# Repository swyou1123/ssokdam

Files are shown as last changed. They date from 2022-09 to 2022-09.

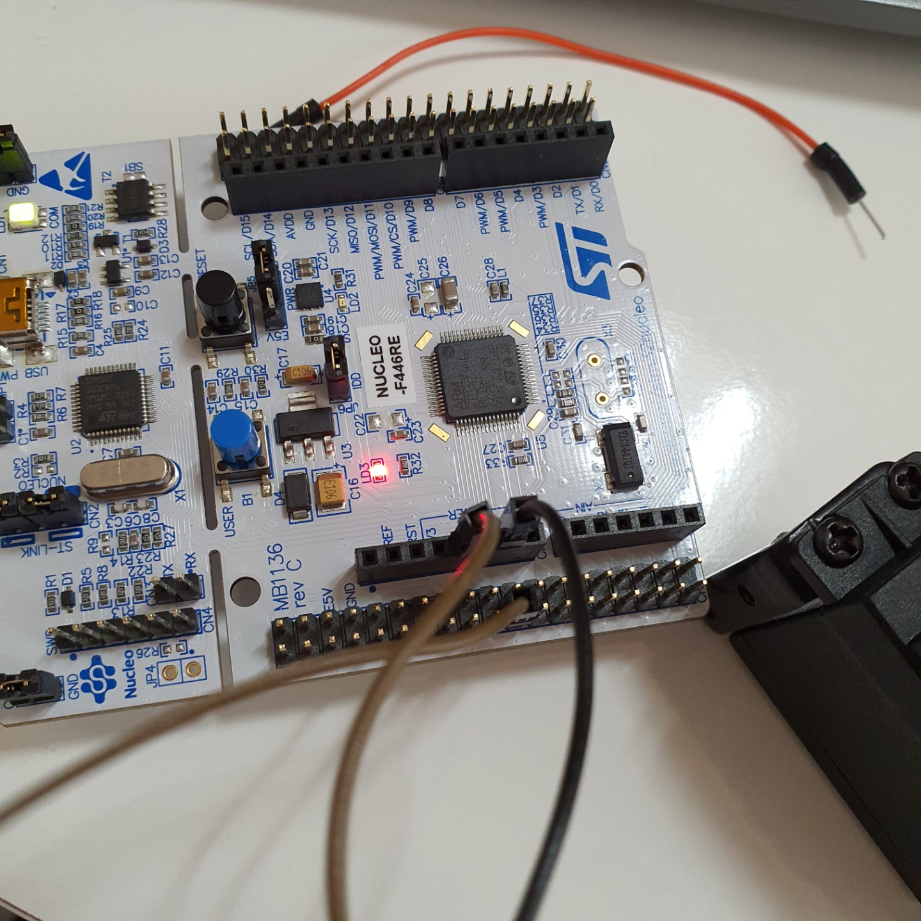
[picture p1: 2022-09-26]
Embedded/STM32/NUCLEO-F446RE/Motor/Servo_Motor/Reference/pinout.jpg

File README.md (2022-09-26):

벨루생선

<div align="center">
  <h1>담배꽁초처리 플랫폼 SSOKDAM</h1>
</div>

## 🧾목차

1. [**서비스 소개**](#-서비스-소개)
2. [**기술 스택**](#%EF%B8%8F-기술-스택)
3. [**시스템 아키텍처**](#-시스템-아키텍쳐)
4. [**웹 주요기능 및 데모영상**](#-웹-주요기능-및-데모영상)
5. [**디바이스 주요기능**](#%EF%B8%8F-디바이스-주요기능)
6. [**UCC 보러가기**](#-ucc-보러가기)
7. [**협업 관리**](#-협업-관리)
8. [**개발 멤버 소개**](#-개발-멤버-소개)
9. [**프로젝트 기간**](#-프로젝트-기간)
10. [**프로젝트 관련 문서**](#-프로젝트-관련-문서)

<br/>

## ✨ 서비스 소개

#### 심각한 바다의 오염문제 😖

> 국내 하루 평균 길에 버려지는 담배꽁초가 무려 **1250**만 개비라고 합니다.<br />
>
> 담배가 그대로 하수구를 통해 바다에 유입돼 바다오염이 되고<br />
>
> 그렇게 바다에서 분해된 미세플라스틱은 오롯이 인간이 먹게됩니다..

#### 바다오염의 해결책 담배꽁초수거 플랫폼 SSOKDAM 💊

##### 바다를 오염시키는 무분별한 담배 꽁초로 부터 지구를 지키기 위해 SSOKDAM을 이용해주세요!

</br>

</br>

## 🛠️ 기술 스택

 <br>

    <br>
    <br/>Styled Components (https://camo.githubusercontent.com/41326de293d3848e2ab0f29bf1680427128757fe6b586ceddf1097cb4eeb5ff7/68747470733a2f2f696d672e736869656c64732e696f2f62616467652f7374796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) HTML5 (https://camo.githubusercontent.com/49fbb99f92674cc6825349b154b65aaf4064aec465d61e8e1f9fb99da3d922a1/68747470733a2f2f696d672e736869656c64732e696f2f62616467652f68746d6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) CSS3 [![Recoil](https://camo.githubusercontent.com/469d51dd03eb2bea7080300247476ae376048af66c8040c2047afa2312e2c052/68747470733a2f2f696d672e736869656c64732e696f2f62616467652f5265636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)](https://camo.githubusercontent.com/469d51dd03eb2bea7080300247476ae376048af66c8040c2047afa2312e2c052/68747470733a2f2f696d672e736869656c64732e696f2f62616467652f5265636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) 

 





</br>

</br>

## 🎛 시스템 아키텍쳐

7 광주_1반_C106조_시스템개략도



#### ERD



#### Backend 디렉토리 구조

```
├─main
│  │   
│  ├─java                
│  │  └─com
│  │      └─ssafy
│  │          └─project
│  │              ├─config        # CORS 및 암호화 설정 폴더
│  │              ├─controller    # 각 도메인별 컨트롤러 있는 폴더
│  │              ├─domain       # 각 DB 테이블 을 설정한 도메인 폴더
│  │              ├─Function      # 추가적인 기능을 모아둔 폴더
│  │              ├─Repository   # 도메인별 JPA Repository 설정한 폴더
│  │              └─Service        # 도메인별 기능을 정의해둔 폴더 
│  └─resources
└─test
    └─java
        └─com
            └─ssafy
                └─project            # 테스트 케이스 있는 폴더
```

#### Frontend 디렉토리 구조

```
───src
    ├─api  		# 백엔드 통신과 필요한 api들을 모아놓은 폴더
    ├─db   		# 백엔드와 통신전에 미리 가상DB를 만들어 테스트를 하는 폴더
    ├─Pages 	# 랜더링되는 페이지가 모아져있는 폴더 
    │  ├─Admin 	# 관리자 페이지가 들어 있는 폴더
    │  │  ├─AdminComplain 	# 불만사항 관련한 관리자 폴더
    │  │  ├─AdminNotice  	# 공지사항 관련한 관리자 폴더
    │  │  └─components 		# 관리자 페이지에서 랜더링되는데 필수적으로 필요한 요소들이 있는 폴더
    │  ├─Auth 		# 회원가입, 로그인 등 인증, 권한과 관련된 페이지가 있는 폴더
    │  ├─Loading 	# 로딩페이지 폴더
    │  ├─Main 		# Client단의 모든 페이지가 있는 폴더
    │  ├─Nav 		# Client단의 Nav바가 있는 폴더
    │  └─Sub 		# Client단에서 부수적으로 필요한 페이지가 있는 폴더
    ├─picture 		# 화면의 사진이 저장돼있는 폴더
    ├─styles 		# 여러가지 style component들이 있는 폴더
    └─ui 			# 간단한 modal이 있는 폴더
```

</br>

</br>

</br>

## 💻 웹 주요기능 및 데모영상

### 1. 회원가입시 외부 API을 이용한 성인인증 및 계좌인증 기능

<div style="display : flex; justify-content : center;">
    
</div>

<div style="display : flex; justify-content : center;">
    
</div>

- 담배와 관련된 서비스이기 때문에 보다 확실한 성인인증 절차를 위해 외부인증 API(iamport)를 이용하여 휴대전화에 등록된 정보에 기반한 성인인증 서비스를 구현하였습니다. 
- 포인트 환전시 현금을 지급해 주어야하기에 본인인증 정보에 기반한 계좌인증 절차를 만들어 확실한 본인의 계좌로 회원가입이 되게 만들었습니다. 

###  2. 디바이스 찾기

<div style="display : flex; justify-content : center;">
    
</div>

- 저희 서비스를 이용하기 위해선 주변에 있는 디바이스를 찾아야합니다. 주변에 있는 디바이스를 탐색하기 위해 지도 API를 이용하여 가장 가까운 디바이스의 위치를 파악하게 하였습니다.
- 지도에 띄워진 사용하기 버튼을 누르면 바로 사용할 수 있게 QR체크 화면으로 넘어갑니다.

###  3. QR접근

<div style="display : flex; justify-content : center;">
    
</div>

- 디바이스를 사용하기 위해 디바이스에 부착된 QR을 찍으면 디바이스 고유번호를 인식하여 디바이스가 열리게 하였습니다.
- 디바이스가 열리고 담배를 투입하면 디바이스 내부로직을 통해 담배여부를 확인하고 결과를 넘겨주게 만들었습니다.
- 담배가 맞다면 "성공페이지"로 아니라면 "실패페이지"로 이동합니다.
- 담배가 맞다면 유저의 최근담배핀 시간이 갱신되게 되고 포인트가 적립이 됩니다.
- 홈화면으로 이동시 다음 이용 가능시간(마지막으로 피고 40분 후)까지 체크를 위해 타이머기능이 있습니다.
- 40분이 지났다면 이용가능, 40분이 지나지 않았다면 타이머가 시작됩니다.

### 4. 포인트적립 및 환전기능

<div style="display : flex; justify-content : center;">
    
</div>

<div style="display : flex; justify-content : center;">
    
</div>

<div style="display : flex; justify-content : center;">
    
</div>

- 담배를 넣어서 포인트가 적립되었다면 포인트 전환신청을 할 수 있습니다.
- 전환신청 내역은 관리자 페이지에 올라가게 되고 관리자가 승인을 해주면 계좌에 돈 입금과 동시에 알림이 가게 됩니다.

### 5. 불만사항접수(불편사항 & 고장신고)

<div style="display : flex; justify-content : center;">
    
</div>
<div style="display : flex; justify-content : center;">
    
</div>

- 불편사항 발생시 글과 내용(이미지 첨부도 가능)을 적게 됩니다. 적힌 글은 관리자 페이지에 올라가게 됩니다.
- 고장사항 발생시에는 글과 내용뿐만 아니라 어디 디바이스인지에 관한 정보가 있어야하기 때문에 QR체크로 디바이스 등록까지 마쳐야 글을 작성할 수 있습니다. 역시 작성된 글을 관리자 페이지로 올라가게 됩니다.
- 고장신고된 디바이스는 관리자가 글을 보며 즉석에서 디바이스 고장상태로 변환시킬 수 있고 고장상태로 변환된 디바이스는 기기정보창에서 빨간색으로 표시가 됩니다.

### 6. 관리자 페이지 디바이스 관리기능

<div style="display : flex; justify-content : center;">
    
</div>

- 문제가 생긴디바이스나 고장난 디바이스를 관리하게 위해 지도상에 설치된 디바이스를 볼 수 있습니다.
- 문제가 생긴디바이스가 있다면 최적경로로 이동하기 위해 네이버지도 api를 통해 최단경로시간을 안내합니다.
- 디바이스 주변동네를 구체적으로 보고 싶다면 로드뷰 기능을 활용할 수도 있습니다.
- 디바이스를 잘 조치했다면 고장상태를 변경할 수 있습니다.

## 🎛️ 디바이스 주요기능

### 0. 디바이스 이미지




###  1. 투입구 개폐

open

- 사용자가 디바이스 상단에 위치한 QR코드를 인식합니다. 사용자 인것이 DB측과의 지속적인 GET요청을 통하여 확인이 되면 내부의 모터가 작동하며 투입구와 내부 덮개가 열리게 됩니다. 이후 담배 인식이 되면 개폐구는 닫히게 됩니다.

###  2. 담배 인식 및 판별

sensor

- 인식부에서는 CDS 조도 센서를 사용하여, 물체가 입구를 통과 할 경우 낮아지는 조도량을 측정하여 
물체 통과를 인식합니다. 인식되지 않을경우 5초후 다음 과정은 생략됩니다.
- 판별부에서는 정확도를 높이기 위해 3가지 센서를 사용하여 담배인지 아닌지를 판별합니다. 
- 비접촉 온도센서에서는 적정 설정온도를, 가스 센서에서는 일정량 이상의 가스를, 공기질 센서에서는 미세먼지 량을 측정하여 3가지 판별 프로세스 중 하나라도 통과하면 담배로 인식됩니다. 

###  3. 담배 분쇄

grind

- 판별부에서 담배로 인식이 된다면 곧바로 분쇄하게 됩니다. 분쇄된 담배는 일반 쓰레기와 분리되어 수거됩니다.

###  4. 처리 후 사용 정보 DB 송신

get

- 판별이 끝난 후 담배 인것이 확인되면 이를 DB측으로 송신합니다. 
- DB에서는 이를 포인트로 적립시킵니다.

###  5. 기기정보 업로드



- 1시간 마다 기기의 정보를 업로드합니다. 
- 위의 이미지 처럼 DB의 Table에 해당되는 JSON 형식으로 POST요청을 보냅니다. 기기 ID, 사용자 이름, 기기 상태, 쓰레기 통 용량, 배터리 등의 정보를 관리자 측으로 송신합니다.

</br>

</br>

## 🎥 UCC 보러가기

[보러가기](https://www.youtube.com/watch?v=OL8DLIg1nm4)

</br>

</br>

## 🙌 협업 관리







## 🧑‍💻 개발 멤버 소개

<table>
    <tr>
        <td height="140px" align="center"> <a href="https://github.com/Owenkim9720">
             <br><br> 👑 김도원 <br>(Embedded) </a> <br></td>
        <td height="140px" align="center"> <a href="https://github.com/kiki249049">
             <br><br> 🙂 김강현 <br>(Front-End) </a> <br></td>
        <td height="140px" align="center"> <a href="https://github.com/dm0114">
             <br><br> 😆 권덕민 <br>(Front-End) </a> <br></td>
        <td height="140px" align="center"> <a href="https://github.com/swyou1123">
             <br><br> 😁 유승우 <br>(Back-End) </a> <br></td>
        <td height="140px" align="center"> <a href="https://github.com/yoonseonghan">
             <br><br> 🙄 윤성한 <br>(Embedded) </a> <br></td>
    </tr>
    <tr>
        <td align="center">Firmware<br/>3D Modeling</td>
        <td align="center">UI/UX<br/>React</td>
        <td align="center">UI/UX<br/>React</td>
        <td align="center">REST API<br/>CI/CD<br/>Infra<br/></td>
        <td align="center">Firmware</td>
    </tr>
</table>

## ⌛ 프로젝트 기간

### 22.7.11 ~ 22.8.19

- 기획 및 설계 : 22.7.11 ~ 20
- 프로젝트 구현 : 22.7.21 ~ 22.8.16
- 버그 수정 및 산출물 정리 : 22.8.17 ~ 19

## 📖 프로젝트 관련 문서

| 구분 | 링크 |
| --- | --- |
| 와이어프레임 | [웹 와이어프레임 바로가기](/outputs/1.광주_1반_C106조_와이어프레임.pdf)  /  [디바이스 와이어프레임 바로가기](/outputs/3.광주_1반_C106조_임베디드_와이어프레임.pdf) |
| 프로젝트 노션 | [프로젝트 노션 바로가기](https://inquisitive-warrior-3ad.notion.site/PJT1_-IOT-ba584e2f93cf41d8aa36975c0ef51f42) |
| DB덤프 | [DB덤프 바로가기](/exec/03_DB덤프.sql) |
| ERD | [ERD 바로가기](https://www.erdcloud.com/d/fKA2qjd6gNFftuiW6) |
| 빌드/배포 | [빌드/배포 바로가기](/exec/01_광주_1반_C106_빌드%20및배포.pdf) |
| 외부서비스 정보 | [외부서비스 정보 바로가기](/exec/02_광주_1반_C106_외부_서비스_정보.pdf) |
| 시연 시나리오 | [시연 시나리오 바로가기](/exec/04_광주_1반_시연시나리오.pdf) |
| 발표자료 | [발표자료 바로가기](https://drive.google.com/file/d/12lOU1-kJ9XMx_7HsXzjGJ9VWt4gaxyYJ/view) |

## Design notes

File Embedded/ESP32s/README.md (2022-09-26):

ESP32관련 코드 (Arduino file)

Save Convention
1. 테스한 센서 및 모터이름을 디렉토리로 영어로 설정 (ex. /Embedded/Esp32/Sensor/GPS_Sensor) (ex. /Embedded/Esp32/Motor/Servo) 
2. 세부디렉토리(ex. /Embedded/Esp32/Motor/Servo)에는.ino 파일 & md파일 (총2개의 파일로 업로드)
3. 추가적으로 설명이 필요한 부분은 md파일을 이용, 내용을 정리해둔다
4. 이미지 및 동영상 첨부가 필요한경우 Reference파일을 만들어 넣어둔다

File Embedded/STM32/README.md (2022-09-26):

STM32관련 코드 (Cube IDE file)

Save Convention
0. 사용한 보드 이름 디렉토리 들어가기
1. 테스한 센서 및 모터이름을 디렉토리로 영어로 설정 (ex. /Embedded/Esp32/Sensor/GPS_Sensor) (ex. /Embedded/Esp32/Motor/Servo) 
2. 세부디렉토리(ex. /Embedded/Esp32/Motor/Servo)에는 CubeIDE의 Package파일 & md파일 (총2개의 파일로 업로드)
3. 추가적으로 설명이 필요한 부분은 md파일을 이용, 내용을 정리해둔다
4. 이미지 및 동영상 첨부가 필요한경우 Reference파일을 만들어 넣어둔다

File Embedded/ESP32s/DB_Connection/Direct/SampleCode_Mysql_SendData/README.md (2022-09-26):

ESP32s 보드를 이용, 여러 센서데이터를 MySQL 데이터베이스에 올리는 샘플 코드입니다.
해당파일의 "Credential.h" 부분의 내용을 변경하여 사용가능하며, ino파일의 쿼리문을 필요에 맞게 변경하시면 됩니다.

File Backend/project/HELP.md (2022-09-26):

# Getting Started

### Reference Documentation
For further reference, please consider the following sections:

* [Official Gradle documentation](https://docs.gradle.org)
* [Spring Boot Gradle Plugin Reference Guide](https://docs.spring.io/spring-boot/docs/2.7.1/gradle-plugin/reference/html/)
* [Create an OCI image](https://docs.spring.io/spring-boot/docs/2.7.1/gradle-plugin/reference/html/#build-image)
* [Spring Web](https://docs.spring.io/spring-boot/docs/2.7.1/reference/htmlsingle/#web)
* [Thymeleaf](https://docs.spring.io/spring-boot/docs/2.7.1/reference/htmlsingle/#web.servlet.spring-mvc.template-engines)
* [Spring Boot DevTools](https://docs.spring.io/spring-boot/docs/2.7.1/reference/htmlsingle/#using.devtools)
* [Spring Data JPA](https://docs.spring.io/spring-boot/docs/2.7.1/reference/htmlsingle/#data.sql.jpa-and-spring-data)

### Guides
The following guides illustrate how to use some features concretely:

* [Building a RESTful Web Service](https://spring.io/guides/gs/rest-service/)
* [Serving Web Content with Spring MVC](https://spring.io/guides/gs/serving-web-content/)
* [Building REST services with Spring](https://spring.io/guides/tutorials/rest/)
* [Handling Form Submission](https://spring.io/guides/gs/handling-form-submission/)
* [Accessing Data with JPA](https://spring.io/guides/gs/accessing-data-jpa/)
* [Accessing data with MySQL](https://spring.io/guides/gs/accessing-data-mysql/)

### Additional Links
These additional references should also help you:

* [Gradle Build Scans – insights for your project's build](https://scans.gradle.com#gradle)

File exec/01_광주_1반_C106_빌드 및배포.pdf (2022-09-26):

# 빌드 및 배포

## 프로젝트 기간 : 2022:07.04 ~ 8.19

# 삼성SW청년아카데미 광주캠퍼스 7기

## 김도원 김강현 권덕민 윤성한 유승우 정혜원

# 1. 기술스택

구분 | 기술스택 | 상세내용 | 버전

공통

형상관리 | Mattermost, Notion gitlab Jira | - 이슈관리 - 커뮤니케이션 -
BackEnd | DB | MySQL | 5.8
JPA | -
| Java | Spring Boot Zulu | 2.7.2 - Spring
| IDE | IntelliJ | 2022.2
| Build | Gradle | 7.4.1
| WebRTC | Tomcat | 9.0.64
| HTML5 | | - CSS3 -
| JavaScript(ES6) | | -
| IDE | Visual Studio Code | 1.63.2
| mui/material | | 5.9.1
| tanstack/react-query | | 4.0.10
| axios | | 0.27.2
| firebase | | 9.9.2
| formik | | 2.2.9
| kakao | | 0.4.1
| react-kakao-maps-sdk | | 1.1.1
| react-qr-reader | | 2.2.1
| recoil | | 0.7.4
| recoil-persist | | 4.2.0
| sass | | 1.54.1
| react-router-dom | | 6.3.0
| styled-components | | 5.3.5
| yup | | 0.32.11

### FrontEnd

Server | 서버 | AWS EC2 Ubuntu | 20.04.4 LTS - 플랫폼
| 배포 | Docker | 20.10.17
| | Jenkins | 2.364.2

# 2. 상세 내용

□ 개요

아래 그림은 “ssokdam” 서비스의 배포환경 및 CI/CD 배포 흐름도입니다. 팀원들이 각자 작성한 프로젝트를 GitLab에 push 하면, Jenkins Build

Trigger를 통해 FrontEnd와 BackEnd를 빌드하게 됩니다.

Embedded | ESP32 | GPS Sensor | TinyGPSPlus 1.03
| | AirQuailty Sensor
| | WiFi
| | Temp Sensor
| | Gas Sensor
| | CRUD | Arduino JSON 0.10
| | Servo motor | ESP Servo 1.0

<CI/CD 배포 환경>

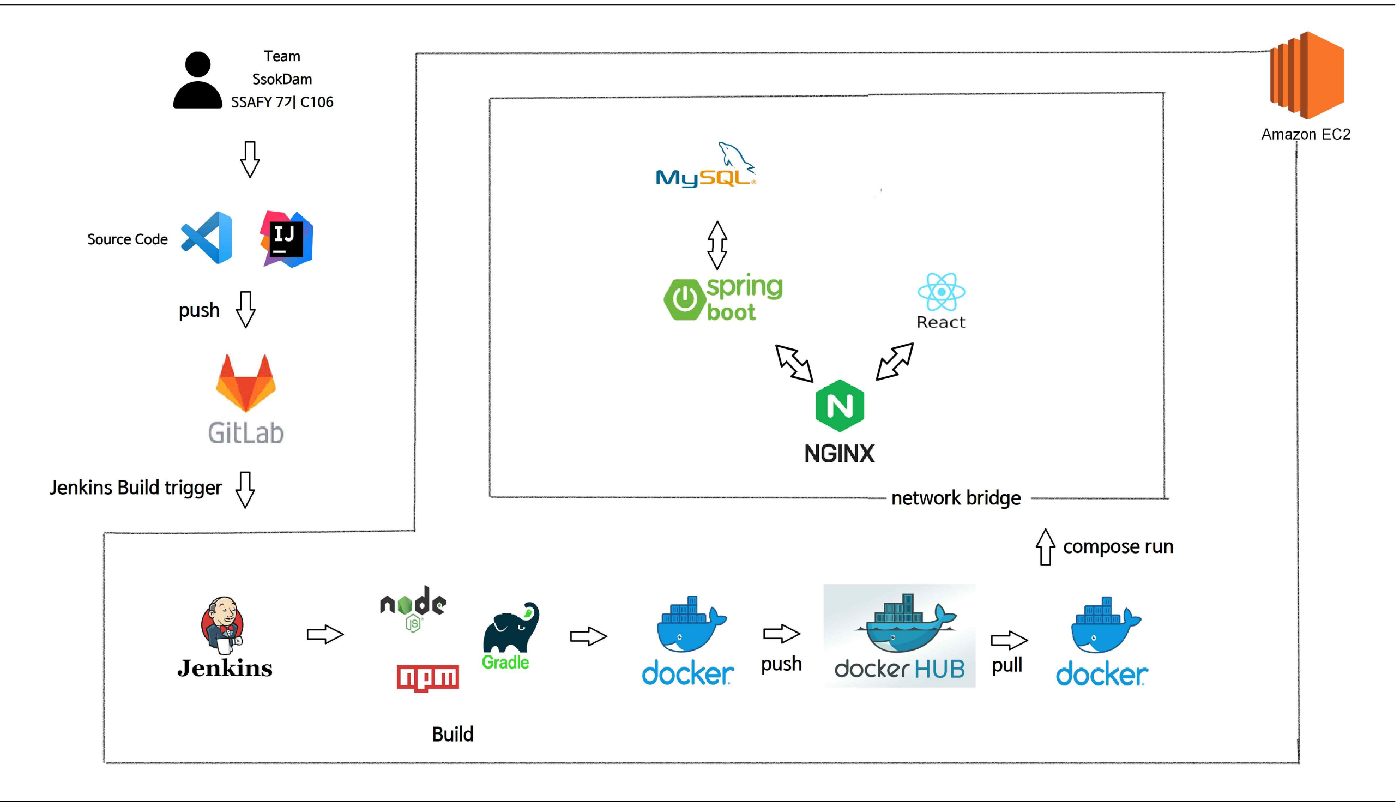
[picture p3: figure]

### 각 프로젝트를 빌드 후에는 Docker 이미지를 만들고 이를 Docker Hub에

### push 합니다. Docker Hub로부터 서비스에 필요한 이미지를 받아와 컨테 이너로 띄웁니다. SSAFY에서 지원받은 EC2 싱글 인스턴스로 인프라를 구 축했습니다. 추후 서비스화를 위해 Nginx는 리버스 프록시 서버로 설정하

### 였습니다. 동시에 Nginx 서버로부터 9090 포트를 BackEnd 서버로 설정 하여 구축했습니다. □ FrontEnd

ㅇ Docker 이미지 생성을 위해 Dockerfile을 작성합니다.

### (해당 파일은 프로젝트 내에 이미 작성되어있습니다.)

### ㅇ docker 이미지 생성

### □ Backend ㅇ Gradle 빌드

ㅇ Docker 이미지 생성을 위해 Dockerfile을 작성합니다.

### (해당 파일은 프로젝트 내에 이미 작성되어있습니다.)

### ㅇ docker 이미지 생성

FROM node:alpine
WORKDIR "/Frontend/usr/src/app"
COPY package.json ./
RUN npm install --save --legacy-peer-deps COPY ./ ./
CMD ["npm","run","start"]

FROM openjdk:17-jdk-alpine
ADD /build/libs/project-0.0.1-SNAPSHOT.jar app.jar ENV JAVA_OPTS=""
ENTRYPOINT ["java","-jar","/app.jar"]

docker build –t syou1123/react:0.1 .

docker build –t syou1123/springboot:0.1 .

./gradlew build

### □ Docker-compose

ㅇ Docker 이미지 생성을 위해 Dockerfile을 작성합니다.

### (해당 파일은 프로젝트 내에 이미 작성되어있습니다.)

version: '3'
services:
nginx:
image: nginx:1.21.5-alpine ports:
- 80:80
- 443:443
volumes:
- /etc/nginx/nginx.conf:/etc/nginx/nginx.conf
- /var/log/nginx:/var/log/nginx
- /etc/letsencrypt:/etc/letsencrypt
- /etc/localtime:/etc/localtime:ro -e TZ=Asia/Seoul - /etc/localtime:/etc/localtime:ro
- /usr/share/zoneinfo/Asia/Seoul:/etc/timezone:ro container_name: myweb-proxy
depends_on:
- web
- api web:

image: swyou1123/react:0.1 ports:
- 3000:3000
volumes:
- /etc/localtime:/etc/localtime:ro -e TZ=Asia/Seoul - /etc/localtime:/etc/localtime:ro
- /usr/share/zoneinfo/Asia/Seoul:/etc/timezone:ro container_name: myweb-web
**** 중략 ****

# 3. 프로퍼티 정의

### □ MySQL

### ㅇ 계정 생성

### ㅇ 스키마 생성

### □ Nginx

### ㅇ 환경 설정

create user 'swyou'@'%' identified by 'qudrlxksdir1!;
grant all privileges on *.* to 'swyou'@'%' with grant option; flush privileges

create database if not exists project collate utf8mb4_general_ci;

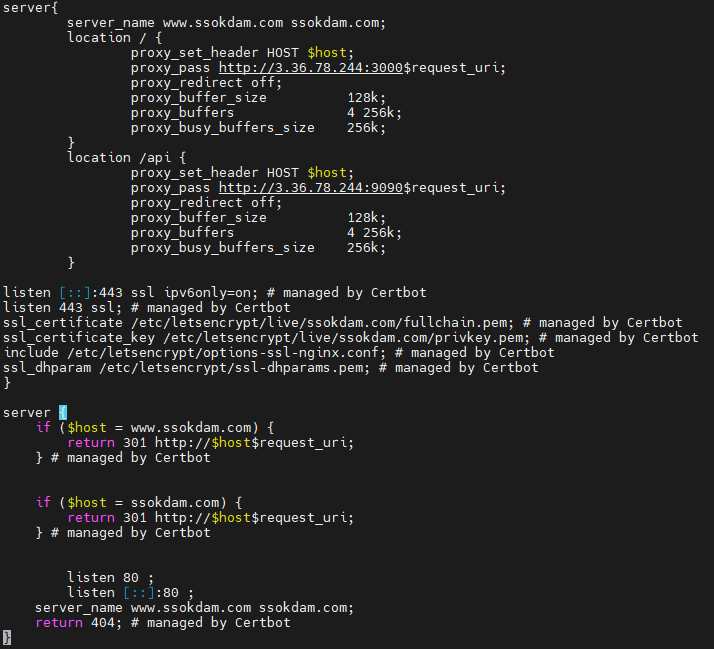
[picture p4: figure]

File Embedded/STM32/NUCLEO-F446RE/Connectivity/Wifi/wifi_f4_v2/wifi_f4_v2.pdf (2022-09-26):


26/07/2022

wifi_f4_v2 Project
Configuration Report

## 1. Description

### 1.1. Project

Project Name | wifi_f4_v2
Board Name | custom
Generated with: | STM32CubeMX 6.6.1
Date | 07/26/2022

### 1.2. MCU

MCU Series | STM32F4
MCU Line | STM32F446
MCU name | STM32F446RETx
MCU Package | LQFP64
MCU Pin number | 64

### 1.3. Core(s) information

Core(s) | Arm Cortex-M4

## 2. Pinout Configuration

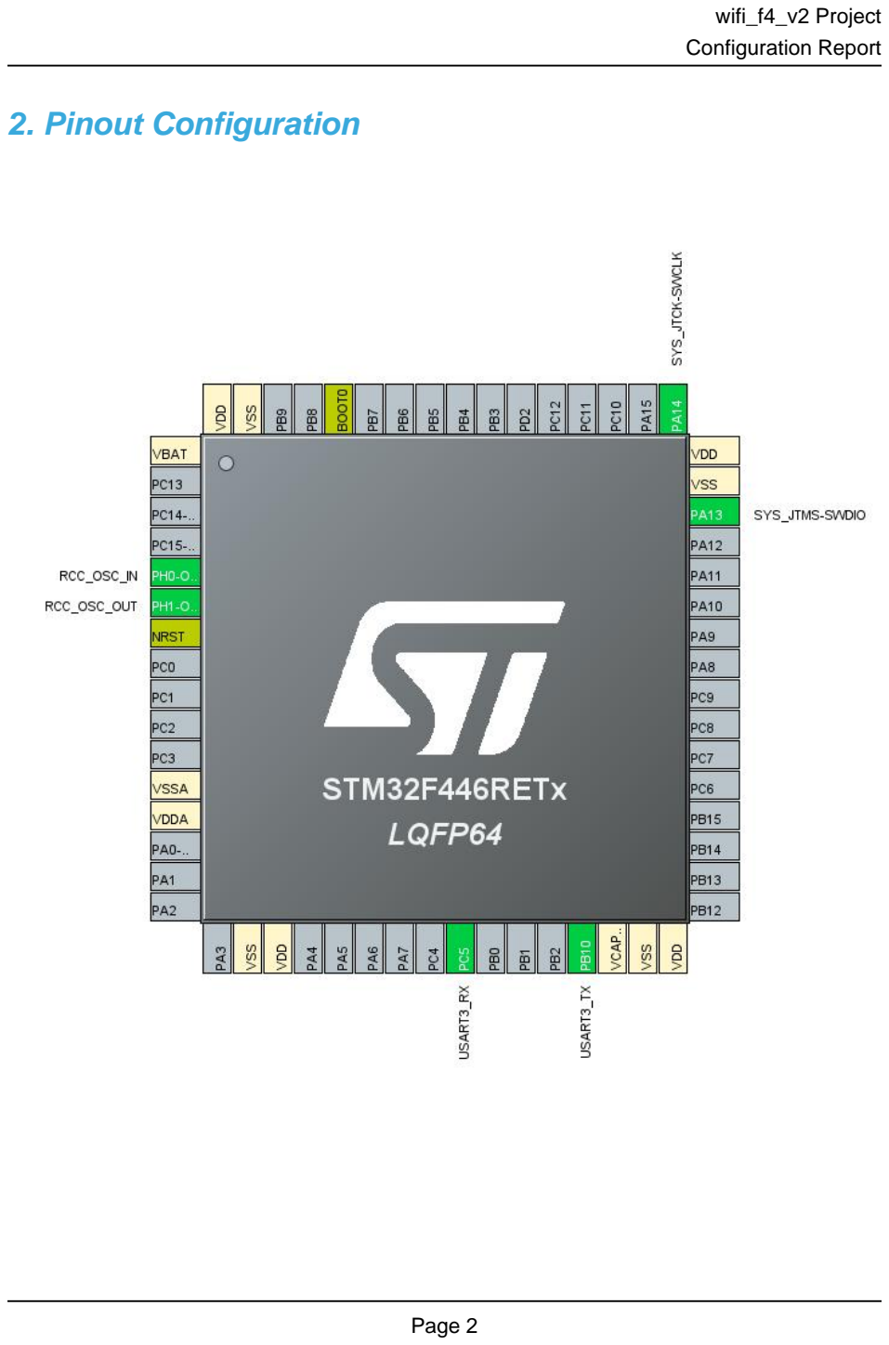
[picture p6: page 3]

## 3. Pins Configuration

Pin Number LQFP64 | Pin Name (function after reset) | Pin Type | Alternate Function(s) | Label
1 | VBAT | Power
5 | PH0-OSC_IN | I/O | RCC_OSC_IN
6 | PH1-OSC_OUT | I/O | RCC_OSC_OUT
7 | NRST | Reset
12 | VSSA | Power
13 | VDDA | Power
18 | VSS | Power
19 | VDD | Power
25 | PC5 | I/O | USART3_RX
29 | PB10 | I/O | USART3_TX
30 | VCAP_1 | Power
31 | VSS | Power
32 | VDD | Power
46 | PA13 | I/O | SYS_JTMS-SWDIO
47 | VSS | Power
48 | VDD | Power
49 | PA14 | I/O | SYS_JTCK-SWCLK
60 | BOOT0 | Boot
63 | VSS | Power
64 | VDD | Power

## 4. Clock Tree Configuration

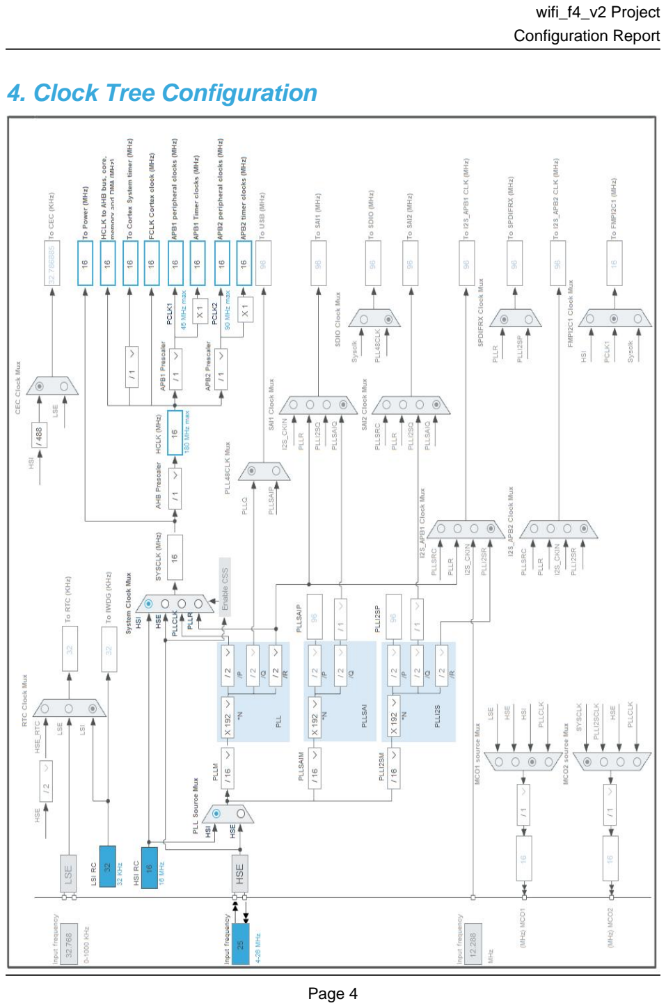
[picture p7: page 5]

## 5. Software Project

### 5.1. Project Settings

Name | Value
Project Name | wifi_f4_v2
Project Folder | C:\Users\multicampus\STM32CubeIDE\workspace_1.10.1\wifi_f4_v2
Toolchain / IDE | STM32CubeIDE
Firmware Package Name and Version | STM32Cube FW_F4 V1.27.1
Application Structure | Advanced
Generate Under Root | Yes
Do not generate the main() | No
Minimum Heap Size | 0x200
Minimum Stack Size | 0x400

### 5.2. Code Generation Settings

Name | Value
STM32Cube MCU packages and embedded software | Copy only the necessary library files
Generate peripheral initialization as a pair of '.c/.h' files | No
Backup previously generated files when re-generating | No
Keep User Code when re-generating | Yes
Delete previously generated files when not re-generated | Yes
Set all free pins as analog (to optimize the power consumption) | No
Enable Full Assert | No

### 5.3. Advanced Settings - Generated Function Calls

Rank | Function Name | Peripheral Instance Name
1 | SystemClock_Config | RCC
2 | MX_GPIO_Init | GPIO
3 | MX_USART3_UART_Init | USART3

## 6. Power Consumption Calculator report

### 6.1. Microcontroller Selection

Series | STM32F4
Line | STM32F446
MCU | STM32F446RETx
Datasheet | DS10693_Rev6

### 6.2. Parameter Selection

Temperature | 25
Vdd | 3.3

### 6.3. Battery Selection

Battery | Li-SOCL2(A3400)
Capacity | 3400.0 mAh
Self Discharge | 0.08 %/month
Nominal Voltage | 3.6 V
Max Cont Current | 100.0 mA
Max Pulse Current | 200.0 mA
Cells in series | 1
Cells in parallel | 1

### 6.4. Sequence

Step | Step1 | Step2
Mode | RUN | STOP_UDM (Under Drive)
Vdd | 3.3 | 3.3
Voltage Source | Battery | Battery
Range | Scale1-High | No Scale
Fetch Type | RAM/FLASH/REGON/ART/P REFETCH | n/a
CPU Frequency | 180 MHz | 0 Hz
Clock Configuration | HSE PLL | Regulator_LP Flash-PwrDwn
Clock Source Frequency | 4 MHz | 0 Hz
Peripherals
Additional Cons. | 0 mA | 0 mA
Average Current | 46 mA | 55 µA
Duration | 0.1 ms | 0.9 ms
DMIPS | 225.0 | 0.0
Ta Max | 98.02 | 104.99
Category | In DS Table | In DS Table

### 6.5. Results

Sequence Time | 1 ms | Average Current | 4.65 mA
Battery Life | 1 month | Average DMIPS | 225.0 DMIPS

### 6.6. Chart

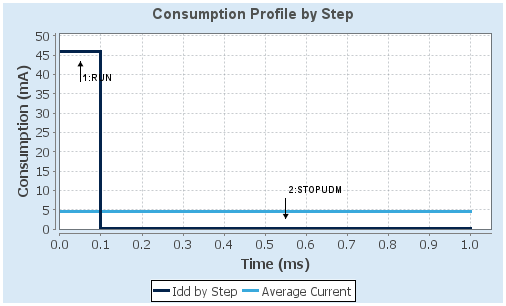
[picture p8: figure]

## 7. Peripherals and Middlewares Configuration

### 7.1. RCC

High Speed Clock (HSE): Crystal/Ceramic Resonator
7.1.1. Parameter Settings:

System Parameters:

VDD voltage (V) | 3.3
Instruction Cache | Enabled
Prefetch Buffer | Enabled
Data Cache | Enabled
Flash Latency(WS) | 0 WS (1 CPU cycle)
RCC Parameters:
HSI Calibration Value | 16
TIM Prescaler Selection | Disabled
HSE Startup Timout Value (ms) | 100
LSE Startup Timout Value (ms) | 5000
Power Parameters:
Power Regulator Voltage Scale | Power Regulator Voltage Scale 3
Power Over Drive | Disabled

### 7.2. SYS

Debug: Serial Wire

### 7.3. USART3

Mode: Asynchronous
7.3.1. Parameter Settings:

Basic Parameters:

Baud Rate | 115200
Word Length | 8 Bits (including Parity)
Parity | None
Stop Bits | 1
Advanced Parameters:
Data Direction | Receive and Transmit
Over Sampling | 16 Samples

* User modified value

## 8. System Configuration

### 8.1. GPIO configuration

IP | Pin | Signal | GPIO mode | GPIO pull/up pull down | Max Speed | User Label
RCC | PH0-OSC_IN | RCC_OSC_IN | n/a | n/a | n/a
| PH1-OSC_OUT | RCC_OSC_OUT | n/a | n/a | n/a
SYS | PA13 | SYS_JTMS-SWDIO | n/a | n/a | n/a
| PA14 | SYS_JTCK-SWCLK | n/a | n/a | n/a
USART3 | PC5 | USART3_RX | Alternate Function Push Pull | No pull-up and no pull-down | Very High *
| PB10 | USART3_TX | Alternate Function Push Pull | No pull-up and no pull-down | Very High *

### 8.2. DMA configuration

nothing configured in DMA service

### 8.3. NVIC configuration

8.3.1. NVIC
Interrupt Table | Enable | Preenmption Priority | SubPriority
Non maskable interrupt | true | 0 | 0
Hard fault interrupt | true | 0 | 0
Memory management fault | true | 0 | 0
Pre-fetch fault, memory access fault | true | 0 | 0
Undefined instruction or illegal state | true | 0 | 0
System service call via SWI instruction | true | 0 | 0
Debug monitor | true | 0 | 0
Pendable request for system service | true | 0 | 0
System tick timer | true | 15 | 0
USART3 global interrupt | true | 0 | 0
PVD interrupt through EXTI line 16 | unused
Flash global interrupt | unused
RCC global interrupt | unused
FPU global interrupt | unused
8.3.2. NVIC Code generation
Enabled interrupt Table | Select for init sequence ordering | Generate IRQ handler | Call HAL handler
Non maskable interrupt | false | true | false
Hard fault interrupt | false | true | false
Memory management fault | false | true | false
Pre-fetch fault, memory access fault | false | true | false
Undefined instruction or illegal state | false | true | false
System service call via SWI instruction | false | true | false
Debug monitor | false | true | false
Pendable request for system service | false | true | false
System tick timer | false | true | true
USART3 global interrupt | false | true | true

* User modified value

## 9. System Views

9.1. Category view
9.1.1. Current

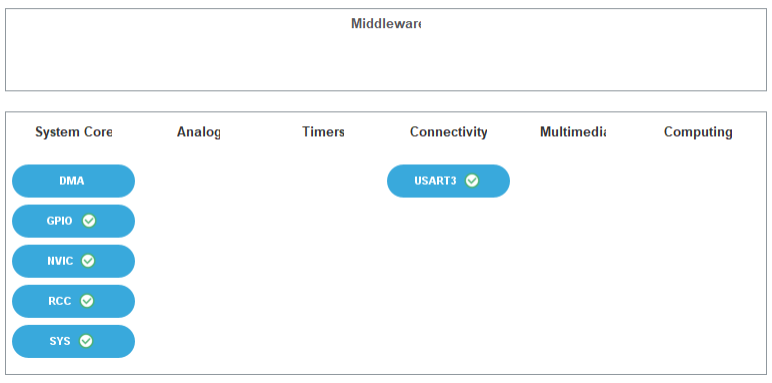
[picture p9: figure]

## 10. Docs & Resources

Type | Link
Presentations | https://www.st.com/resource/en/product_presentation/stm32-stm8_embedded_software_solutions.pdf
Presentations | https://www.st.com/resource/en/product_presentation/stm32_eval-tools_portfolio.pdf
Presentations | https://www.st.com/resource/en/product_presentation/stm32_stm8_functi onal-safety-packages.pdf
Presentations | https://www.st.com/resource/en/product_presentation/stm32-stm8_software_development_tools.pdf
Training Material | https://www.st.com/resource/en/sales_guide/sg_sc2154.pdf
Flyers | https://www.st.com/resource/en/flyer/flnucleolrwan.pdf
Flyers | https://www.st.com/resource/en/flyer/flstm32nucleo.pdf
Flyers | https://www.st.com/resource/en/flyer/flstmcsuite.pdf
Flyers | https://www.st.com/resource/en/flyer/flstm32trust.pdf
Product Certifications | https://www.st.com/resource/en/certification_document/stm32_authentication_can.pdf
Application Notes | https://www.st.com/resource/en/application_note/an1181-electrostatic-discharge-sensitivity-measurement-stmicroelectronics.pdf
Application Notes | https://www.st.com/resource/en/application_note/an1709-emc-design-guide-for-stm8-stm32-and-legacy-mcus-stmicroelectronics.pdf
Application Notes | https://www.st.com/resource/en/application_note/an2606-stm32-microcontroller-system-memory-boot-mode-stmicroelectronics.pdf
Application Notes | https://www.st.com/resource/en/application_note/an2639-soldering-recommendations-and-package-information-for-leadfree-ecopack-mcus-and-mpus-stmicroelectronics.pdf
Application Notes | https://www.st.com/resource/en/application_note/an2834-how-to-get-the-best-adc-accuracy-in-stm32-microcontrollers-stmicroelectronics.pdf
Application Notes | https://www.st.com/resource/en/application_note/an2867-oscillator-design-guide-for-stm8afals-stm32-mcus-and-mpus-stmicroelectronics.pdf
Application Notes | https://www.st.com/resource/en/application_note/an2945-stm8s-and-

| stm32-mcus-a-consistent-832bit-product-line-for-painless-migration-stmicroelectronics.pdf
Application Notes | https://www.st.com/resource/en/application_note/an3070-managing-the-driver-enable-signal-for-rs485-and-iolink-communications-with-the-stm32s-usart-stmicroelectronics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
Application Notes | https://www.st.com/resource/en/application_note/an3126-audio-and-waveform-generation-using-the-dac-in-stm32-products-stmicroelectronics.pdf
Application Notes | https://www.st.com/resource/en/application_note/an3154-can-protocol-used-in-the-stm32-bootloader-stmicroelectronics.pdf
Application Notes | https://www.st.com/resource/en/application_note/an3155-usart-protocol-used-in-the-stm32-bootloader-stmicroelectronics.pdf
Application Notes | https://www.st.com/resource/en/application_note/an3156-usb-dfu-protocol-used-in-the-stm32-bootloader-stmicroelectronics.pdf
Application Notes | https://www.st.com/resource/en/application_note/an3364-migration-and-compatibility-guidelines-for-stm32-microcontroller-applications-stmicroelectronics.pdf
Application Notes | https://www.st.com/resource/en/application_note/an3997-audio-playback-and-recording-using-the-stm32f4discovery-stmicroelectronics.pdf
Application Notes | https://www.st.com/resource/en/application_note/an3998-pdm-audio-software-decoding-on-stm32-microcontrollers-stmicroelectronics.pdf
Application Notes | https://www.st.com/resource/en/application_note/an4013-stm32-crossseries-timer-overview-stmicroelectronics.pdf
Application Notes | https://www.st.com/resource/en/application_note/an4031-using-the-stm32f2-stm32f4-and-stm32f7-series-dma-controller-stmicroelectronics.pdf
Application Notes | https://www.st.com/resource/en/application_note/an4221-i2c-protocol-used-in-the-stm32-bootloader-stmicroelectronics.pdf
Application Notes | https://www.st.com/resource/en/application_note/an4229-how-to-implement-a-vocoder-solution-using-stm32-microcontrollers-stmicroelectronics.pdf
Application Notes | https://www.st.com/resource/en/application_note/an4230-stm32- microcontroller-random-number-generation-validation-using-the-nist-

| statistical-test-suite-stmicroelectronics.pdf
Application Notes | https://www.st.com/resource/en/application_note/an4277-using-stm32-device-pwm-shutdown-features-for-motor-control-and-digital-power-conversion-stmicroelectronics.pdf
Application Notes | https://www.st.com/resource/en/application_note/an4286-spi-protocol-used-in-the-stm32-bootloader-stmicroelectronics.pdf
Application Notes | https://www.st.com/resource/en/application_note/an4488-getting-started-with-stm32f4xxxx-mcu-hardware-development-stmicroelectronics.pdf
Application Notes | https://www.st.com/resource/en/application_note/an4566-extending-the-dac-performance-of-stm32-microcontrollers-stmicroelectronics.pdf
Application Notes | https://www.st.com/resource/en/application_note/an4640-peripherals-interconnections-on-stm32f4057xx-stm32f4157xx-stm32f42xxx-stm32f43xxx-stm32f446xx-and-stm32f469479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
Application Notes | https://www.st.com/resource/en/application_note/an4655-virtually-increasing-the-number-of-serial-communication-peripherals-in-stm32-applications-stmicroelectronics.p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
Application Notes | https://www.st.com/resource/en/application_note/an4658-migration-of-applications-from-stm32f429439-lines-to-stm32f446-line-stmicroelectronics.pdf
Application Notes | https://www.st.com/resource/en/application_note/an4739-stm32cube-firmware-examples-for-stm32f4-series-stmicroelectronics.pdf
Application Notes | https://www.st.com/resource/en/application_note/an4750-handling-of-soft-errors-in-stm32-applications-stmicroelectronics.pdf
Application Notes | https://www.st.com/resource/en/application_note/an4759-using-the-hardware-realtime-clock-rtc-and-the-tamper-management-unit-tamp-with-stm32-microcontrollers-stmicroe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
Application Notes | https://www.st.com/resource/en/application_note/an4776-generalpurpose-timer-cookbook-for-stm32-microcontrollers-stmicroelectronics.pdf
Application Notes | https://www.st.com/resource/en/application_note/an4803-highspeed-si-simulations-using-ibis-and-boardlevel-simulations-using-hyperlynx-si-on-stm32-mcus-and-mpus-stmic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
Application Notes | https://www.st.com/resource/en/application_note/an4838-managing-memory-protection-unit-in-stm32-mcus-stmicroelectronics.pdf

Application Notes | https://www.st.com/resource/en/application_note/an4850-stm32-mcus-spreadspectrum-clock-generation-principles-properties-and-implementation-stmicroelectronics.pdf
Application Notes | https://www.st.com/resource/en/application_note/an4879-usb-hardware-and-pcb-guidelines-using-stm32-mcus-stmicroelectronics.pdf
Application Notes | https://www.st.com/resource/en/application_note/an4908-stm32-usart-automatic-baud-rate-detection-stmicroelectronics.pdf
Application Notes | https://www.st.com/resource/en/application_note/an4989-stm32-microcontroller-debug-toolbox-stmicroelectronics.pdf
Application Notes | https://www.st.com/resource/en/application_note/an4995-using-an-electromyogram-technique-to-detect-muscle-activity-stmicroelectronics.pdf
Application Notes | https://www.st.com/resource/en/application_note/an5020-digital-camera-interface-dcmi-on-stm32-mcus-stmicroelectronics.pdf
Application Notes | https://www.st.com/resource/en/application_note/an5027-interfacing-pdm-digital-microphones-using-stm32-mcus-and-mpus-stmicroelectronics.pdf
Application Notes | https://www.st.com/resource/en/application_note/an5036-thermal-management-guidelines-for-stm32-applications-stmicroelectronics.pdf
Application Notes | https://www.st.com/resource/en/application_note/an5073-receiving-spdif-audio-stream-with-the-stm32f4f7h7-series-stmicroelectronics.pdf
Application Notes | https://www.st.com/resource/en/application_note/an5156-introduction-to-stm32-microcontrollers-security-stmicroelectronics.pdf
Application Notes | https://www.st.com/resource/en/application_note/an5225-usb-typec-power-delivery-using-stm32-mcus-and-mpus-stmicroelectronics.pdf
Application Notes | https://www.st.com/resource/en/application_note/an5543-enhanced-methods-to-handle-spi-communication-on-stm32-devices-stmicroelectronics.pdf
Application Notes | https://www.st.com/resource/en/application_note/an4760-quadspi-interface-on-stm32-microcontrollers-and-microprocessors--stmicroelectronics.pdf
Application Notes | https://www.st.com/resource/en/application_note/an4899-stm32-microcontroller-gpio-hardware-settings-and-lowpower-consumption-stmicroelectronics.pdf

Application Notes for related Tools & Software | https://www.st.com/resource/en/application_note/an1202_freertos_guide-freertos-guide-stmicroelectronics.pdf
Application Notes for related Tools & Software | https://www.st.com/resource/en/application_note/an1602_semihosting_in_truestudio-how-to-do-semihosting-in-truestudio-stmicroelectronics.pdf
Application Notes for related Tools & Software | https://www.st.com/resource/en/application_note/an1801_stm32cubeprogrammer_in_truestudio-installing-stm32cubeprogrammer-in-truestudio-stmicroelectronics.pdf
Application Notes for related Tools & Software | https://www.st.com/resource/en/application_note/atollic_editing_keyboard_shortcuts-atollic-editing-keyboard-shortcuts-stmicroelectronics.pdf
Application Notes for related Tools & Software | https://www.st.com/resource/en/application_note/iar_to_atollic_truestudio_migration_guide-truestudio-for-arm-migration-guide-iar-embedded-workbench-to-truestudio-stm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
Application Notes for related Tools & Software | https://www.st.com/resource/en/application_note/stm32cubemx_installation_in_truestudio-stm32cubemx-installation-in-truestudio-stmicroelectronics.pdf
Application Notes for related Tools & Software | https://www.st.com/resource/en/application_note/an2656-stm32f10xxx-lcd-glass-driver-firmware-stmicroelectronics.pdf
Application Notes for related Tools & Software | https://www.st.com/resource/en/application_note/an2790-tft-lcd-interfacing-with-the-highdensity-stm32f10xxx-fsmc-stmicroelectronics.pdf
Application Notes for related Tools & Software | https://www.st.com/resource/en/application_note/an3078-stm32-inapplication-programming-over-the-ic-bus-stmicroelectronics.pdf
Application Notes for related Tools & Software | https://www.st.com/resource/en/application_note/an3116-stm32s-adc-modes-and-their-applications-stmicroelectronics.pdf
Application Notes for related Tools & Software | https://www.st.com/resource/en/application_note/an3174-implementing-receivers-for-infrared-remote-control-protocols-using-stm32f10xxx-microcontrollers-stmicroelectro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
Application Notes | https://www.st.com/resource/en/application_note/an3241-qvga-tftlcd-

for related Tools & Software | direct-drive-using-the-stm32f10xx-fsmc-peripheral-stmicroelectronics.pdf
Application Notes for related Tools & Software | https://www.st.com/resource/en/application_note/an3307-guidelines-for-obtaining-iec-60335-class-b-certification-for-any-stm32-application-stmicroelectronics.pdf
Application Notes for related Tools & Software | https://www.st.com/resource/en/application_note/an3364-migration-and-compatibility-guidelines-for-stm32-microcontroller-applications-stmicroelectronics.pdf
Application Notes for related Tools & Software | https://www.st.com/resource/en/application_note/an3965-stm32f40xstm32f41x-inapplication-programming-using-the-usart-stmicroelectronics.pdf
Application Notes for related Tools & Software | https://www.st.com/resource/en/application_note/an3969-eeprom-emulation-in-stm32f40xstm32f41x-microcontrollers-stmicroelectronics.pdf
Application Notes for related Tools & Software | https://www.st.com/resource/en/application_note/an3990-upgrading-stm32f4discovery-board-firmware-using-a-usb-key-stmicroelectronics.pdf
Application Notes for related Tools & Software | https://www.st.com/resource/en/application_note/an3997-audio-playback-and-recording-using-the-stm32f4discovery-stmicroelectronics.pdf
Application Notes for related Tools & Software | https://www.st.com/resource/en/application_note/an3998-pdm-audio-software-decoding-on-stm32-microcontrollers-stmicroelectronics.pdf
Application Notes for related Tools & Software | https://www.st.com/resource/en/application_note/an4044-floating-point-unit-demonstration-on-stm32-microcontrollers-stmicroelectronics.pdf
Application Notes for related Tools & Software | https://www.st.com/resource/en/application_note/an4187-using-the-crc-peripheral-in-the-stm32-family-stmicroelectronics.pdf
Application Notes for related Tools & Software | https://www.st.com/resource/en/application_note/an4323-getting-started-with-stemwin-library-stmicroelectronics.pdf

Application Notes
for related Tools

https://www.st.com/resource/en/application_note/an4365-using-stm32f4-mcu-power-modes-with-best-dynamic-efficiency-stmicroelectronics.pdf

& Software
Application Notes for related Tools & Software | https://www.st.com/resource/en/application_note/an4435-guidelines-for-obtaining-ulcsaiec-607301603351-class-b-certification-in-any-stm32-application-stmicroelectroni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
Application Notes for related Tools & Software | https://www.st.com/resource/en/application_note/an4457-implementing-an-emulated-uart-on-stm32f4-microcontrollers-stmicroelectronics.pdf
Application Notes for related Tools & Software | https://www.st.com/resource/en/application_note/an4499-stm32--nrf51822-bluetooth-low-energy-system-solution-stmicroelectronics.pdf
Application Notes for related Tools & Software | https://www.st.com/resource/en/application_note/an4502-stm32-smbuspmbus-embedded-software-expansion-for-stm32cube-stmicroelectronics.pdf
Application Notes for related Tools & Software | https://www.st.com/resource/en/application_note/an4657-stm32-inapplication-programming-iap-using-the-usart-stmicroelectronics.pdf
Application Notes for related Tools & Software | https://www.st.com/resource/en/application_note/an4666-parallel-synchronous-transmission-using-gpio-and-dma-stmicroelectronics.pdf
Application Notes for related Tools & Software | https://www.st.com/resource/en/application_note/an4678-full-duplex-spi-emulation-for-stm32f4-microcontrollers-stmicroelectronics.pdf
Application Notes for related Tools & Software | https://www.st.com/resource/en/application_note/an4701-proprietary-code-readout-protection-on-microcontrollers-of-the-stm32f4-series-stmicroelectronics.pdf
Application Notes for related Tools & Software | https://www.st.com/resource/en/application_note/an4739-stm32cube-firmware-examples-for-stm32f4-series-stmicroelectronics.pdf
Application Notes for related Tools & Software | https://www.st.com/resource/en/application_note/an4758-proprietary-code-readout-protection-on-stm32l4-stm32l4-stm32g4-and-stm32wb-series-mcus-stmicroelectronics.pdf
Application Notes for related Tools & Software | https://www.st.com/resource/en/application_note/an4759-using-the-hardware-realtime-clock-rtc-and-the-tamper-management-unit-tamp-with-stm32-microcontrollers-stmicroe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

Application Notes for related Tools & Software | https://www.st.com/resource/en/application_note/an4841-digital-signal-processing-for-stm32-microcontrollers-using-cmsis-stmicroelectronics.pdf
Application Notes for related Tools & Software | https://www.st.com/resource/en/application_note/an4852-programming-an-external-flash-memory-using-the-uart-bootloader-builtin-stm32-microcontrollers-stmicroelectroni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
Application Notes for related Tools & Software | https://www.st.com/resource/en/application_note/an4968-proprietary-code-read-out-protection-pcrop-on-stm32f72xxx-and-stm32f73xxx-microcontrollers-stmicroelectronics.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
Application Notes for related Tools & Software | https://www.st.com/resource/en/application_note/an5054-secure-programming-using-stm32cubeprogrammer-stmicroelectronics.pdf
Application Notes for related Tools & Software | https://www.st.com/resource/en/application_note/an5056-integration-guide-for-the-xcubesbsfu-stm32cube-expansion-package-stmicroelectronics.pdf
Application Notes for related Tools & Software | https://www.st.com/resource/en/application_note/an5360-getting-started-with-projects-based-on-the-stm32mp1-series-in-stm32cubeide-stmicroelectronics.pdf
Application Notes for related Tools & Software | https://www.st.com/resource/en/application_note/an5361-getting-started-with-projects-based-on-dualcore-stm32h7-microcontrollers-in-stm32cubeide-stmicroelectronics.pd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
Application Notes for related Tools & Software | https://www.st.com/resource/en/application_note/an5394-getting-started-with-projects-based-on-the-stm32l5-series-in-stm32cubeide-stmicroelectronics.pdf
Application Notes for related Tools & Software | https://www.st.com/resource/en/application_note/an5418-how-to-build-a-simple-usbpd-sink-application-with-stm32cubemx-stmicroelectronics.pdf
Application Notes for related Tools & Software | https://www.st.com/resource/en/application_note/an5426-migrating-graphics-middleware-projects-from-stm32cubemx-540-to-stm32cubemx-550-stmicroelectronics.pdf
Application Notes for related Tools & Software | https://www.st.com/resource/en/application_note/an5464-position-control-of-a-threephase-permanent-magnet-motor-using-xcubemcsdk-or-xcubemcsdkful-stmicroelectronics.p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
Application Notes | https://www.st.com/resource/en/application_note/an5564-getting-started-

for related Tools & Software | with-projects-based-on-dualcore-stm32wl-microcontrollers-in-stm32cubeide-stmicroelectronics.pdf
Application Notes for related Tools & Software | https://www.st.com/resource/en/application_note/an5698-adapting-the-xcubestl-functional-safety-package-for-stm32-iec-61508-compliant-to-other-safety-standards-stmicr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
Application Notes for related Tools & Software | https://www.st.com/resource/en/application_note/an5731-stm32cubemx-and-stm32cubeide-threadsafe-solution-stmicroelectronics.pdf
Errata Sheets | https://www.st.com/resource/en/errata_sheet/es0298-stm32f446xcxe-device-limitations-stmicroelectronics.pdf
Datasheet | https://www.st.com/resource/en/datasheet/dm00141306.pdf
Programming Manuals | https://www.st.com/resource/en/programming_manual/pm0214-stm32-cortexm4-mcus-and-mpus-programming-manual-stmicroelectronics.pdf
Reference Manuals | https://www.st.com/resource/en/reference_manual/rm0390-stm32f446xx-advanced-armbased-32bit-mcus-stmicroelectronics.pdf
Technical Notes & Articles | https://www.st.com/resource/en/technical_note/tn0516-overview-of-the-stm32f0xf100xxf103xx-and-stm32f2xxf30xf4xx-mcus-pmsm-singledual-foc-sdk-v40-stmicroelectronics.p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
Technical Notes & Articles | https://www.st.com/resource/en/technical_note/tn1163-description-of-wlcsp-for-microcontrollers-and-recommendations-for-its-use-stmicroelectronics.pdf
Technical Notes & Articles | https://www.st.com/resource/en/technical_note/tn1204-tape-and-reel-shipping-media-for-stm32-microcontrollers-in-bga-packages-stmicroelectronics.pdf
Technical Notes & Articles | https://www.st.com/resource/en/technical_note/tn1205-tape-and-reel-shipping-media-for-stm8-and-stm32-microcontrollers-in-fpn-packages-stmicroelectronics.pdf
Technical Notes & Articles | https://www.st.com/resource/en/technical_note/tn1206-tape-and-reel-shipping-media-for-stm8-and-stm32-microcontrollers-in-qfp-packages-stmicroelectronics.pdf
Technical Notes & Articles | https://www.st.com/resource/en/technical_note/tn1207-tape-and-reel-shipping-media-for-stm8-and-stm32-microcontrollers-in-so-packages-stmicroelectronics.pdf

Technical Notes
& Articles

https://www.st.com/resource/en/technical_note/tn1208-tape-and-reelshipping-media-for-stm8-and-stm32-microcontrollers-in-tssop-and-ssoppackages-stmicroelectronics.pdf

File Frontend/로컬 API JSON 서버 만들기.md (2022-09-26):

## 로컬 API JSON 서버 만들기

1. 임시 데이터를 넣을 db.json을 만들어서 넣고 싶은 폴더에 넣습니다(파일명은 원하시는대로 하시면 됩니다)
2. 터미널 환경에서 터미널 경로를 db.json이 들어가있는 폴더로 이동합니다

**pwd** - 현재 경로 확인
**ls** - 그 폴더에 들어있는 파일 목록들 보기
**cd** - 폴더명 - 해당 폴더로 이동_

그런 다음

```null
npx json-server ./db.json(저장한 파일명) --watch --port 8888
```

을 입력하면 해당 json api를 호출 시킬 수 있는 local Url이 생성됩니다.

그리고 ajax나 fetch등을 이용하여 통신 후 처리해주시면 됩니다

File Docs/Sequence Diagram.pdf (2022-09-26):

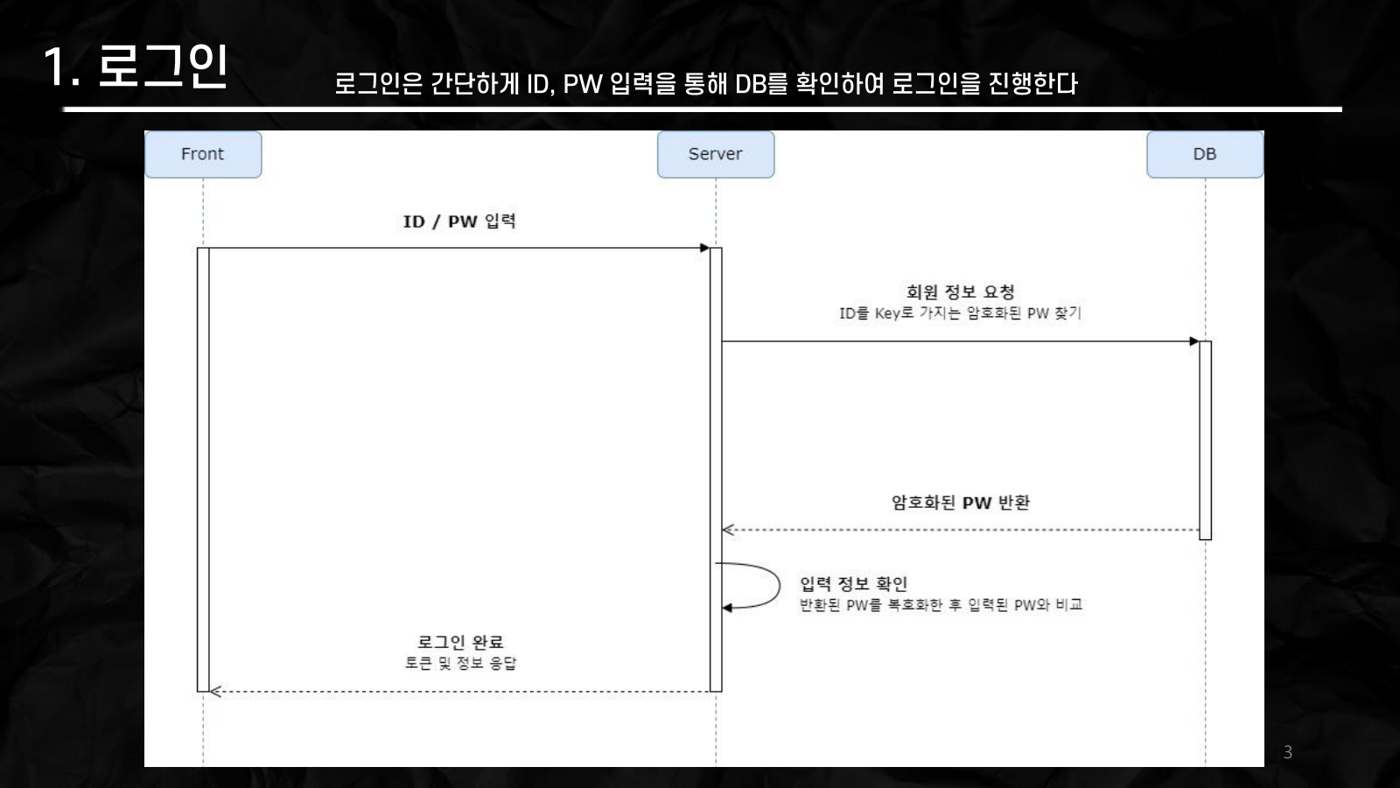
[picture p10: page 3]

–

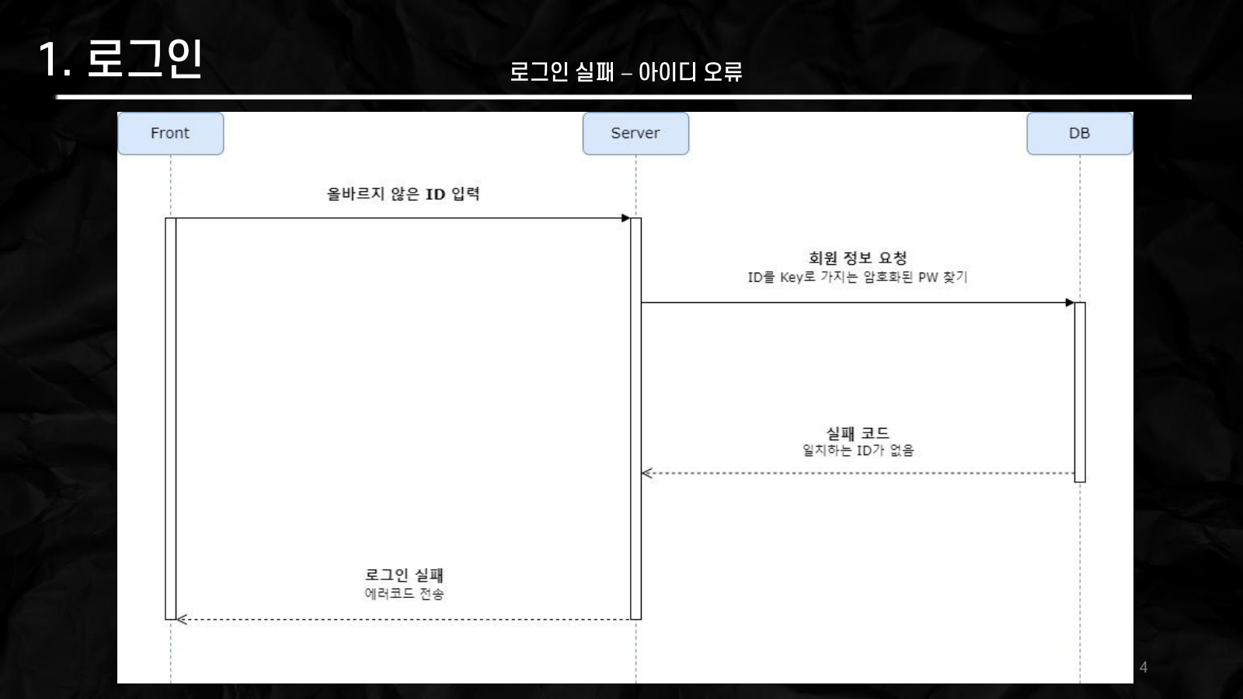
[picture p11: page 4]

–

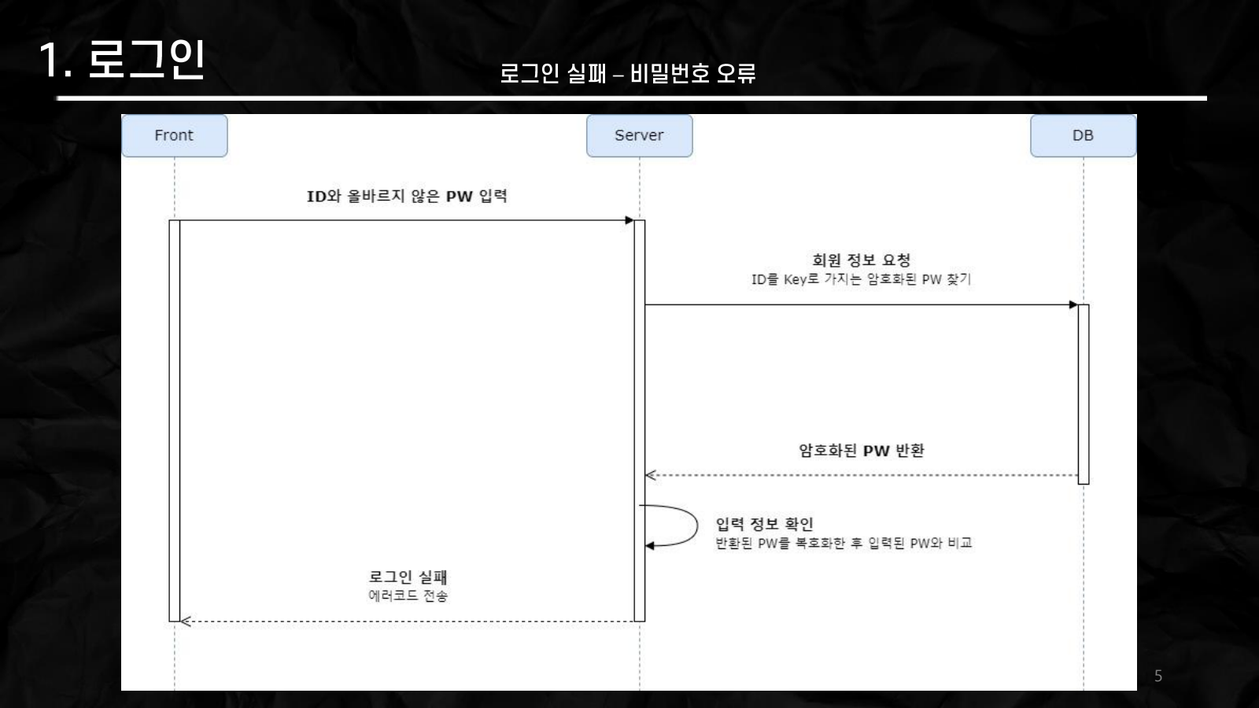
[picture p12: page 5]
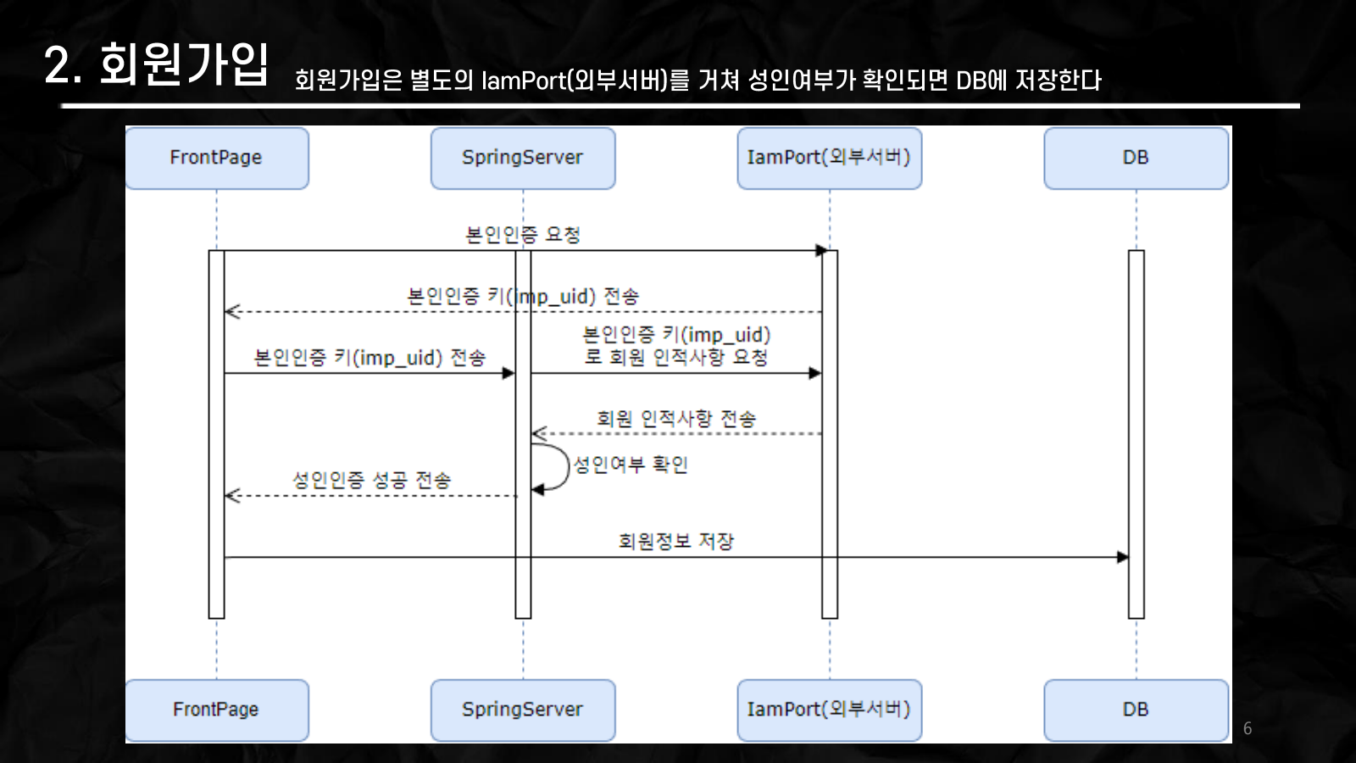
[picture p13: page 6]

–

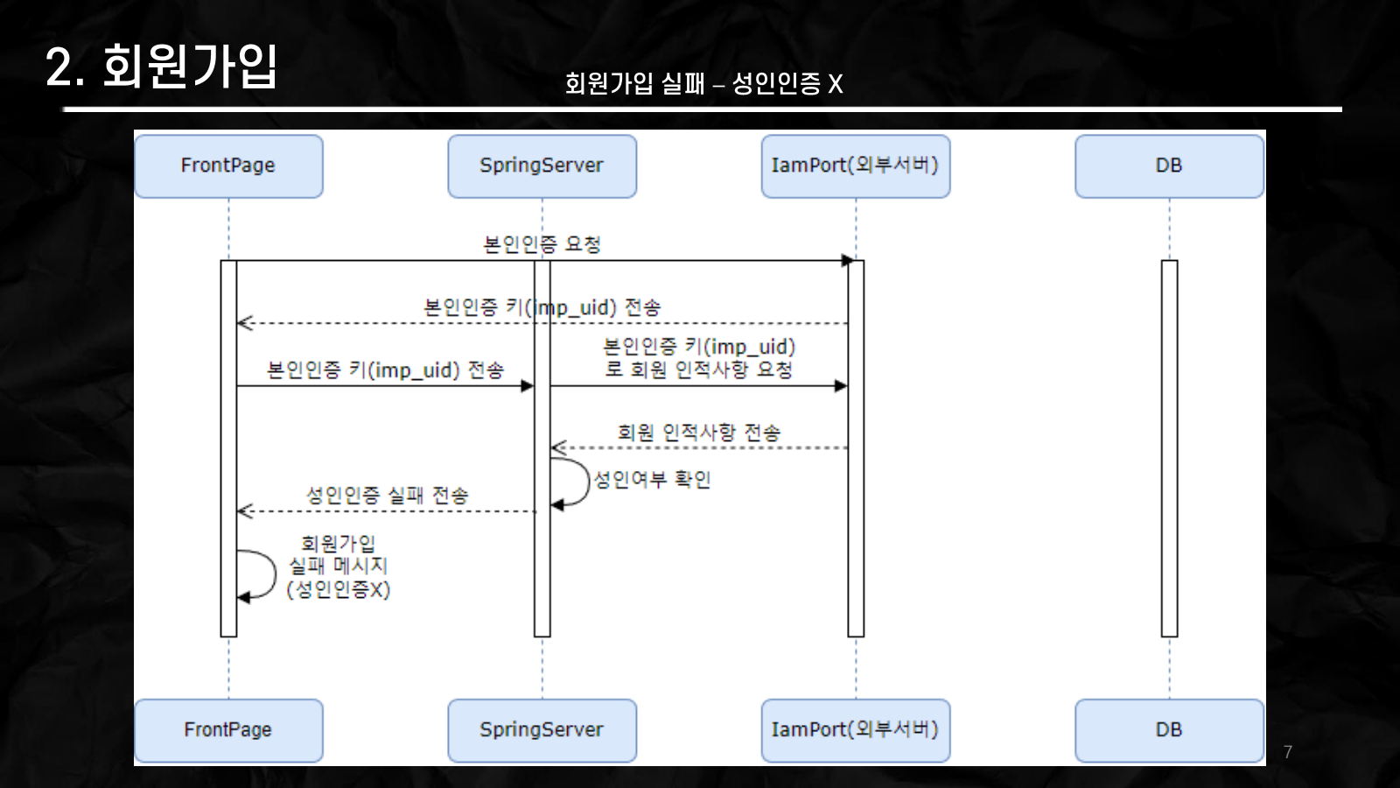
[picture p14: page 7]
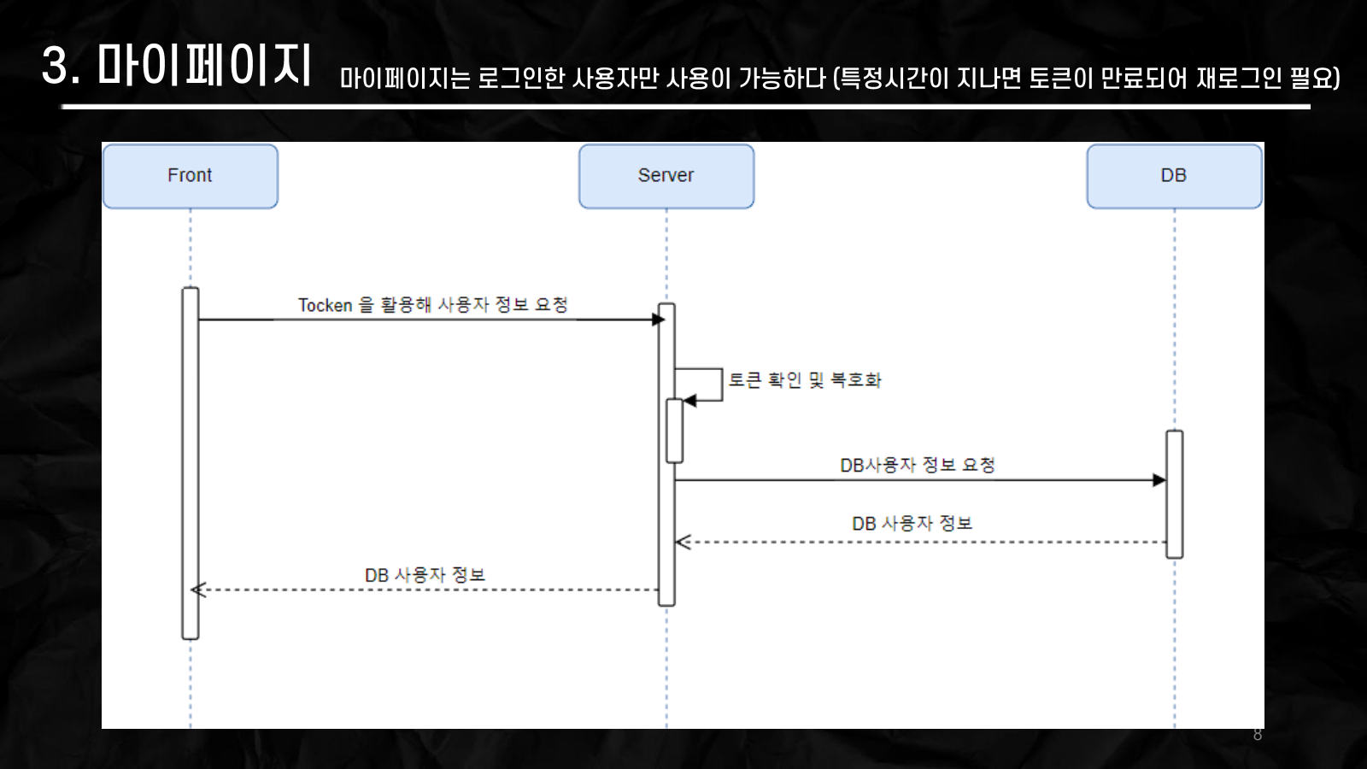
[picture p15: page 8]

–

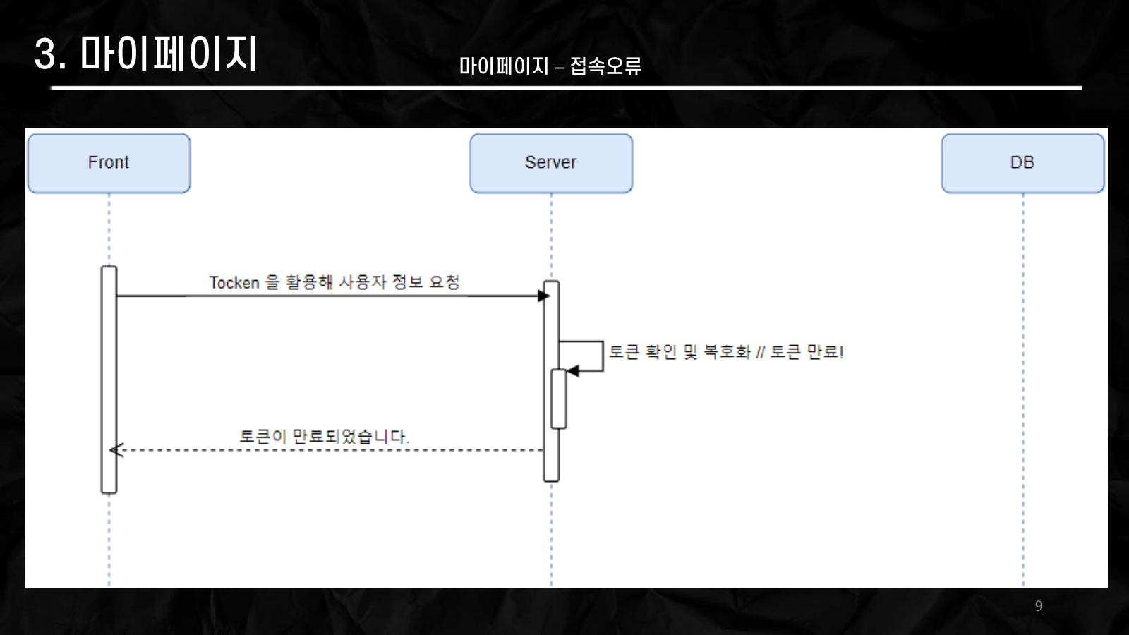
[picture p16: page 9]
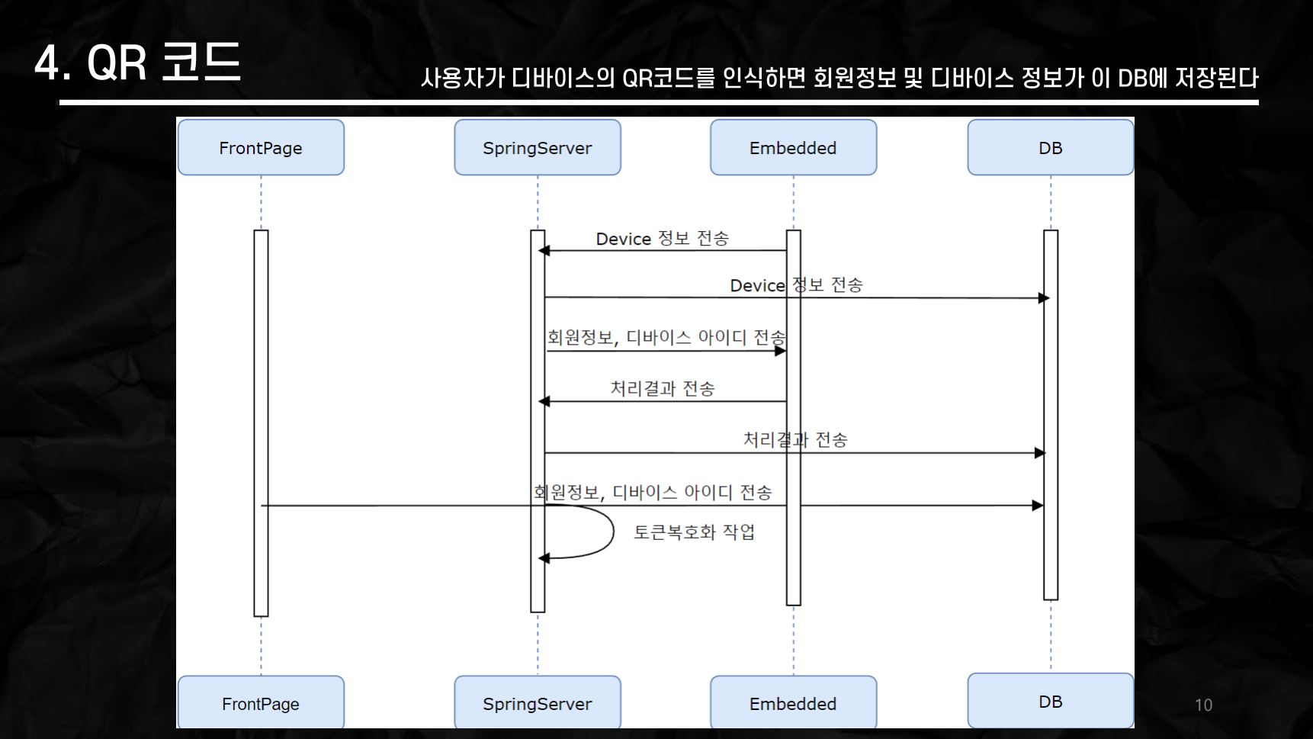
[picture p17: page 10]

7/31/2022 | 10 7/31/2022 | 10

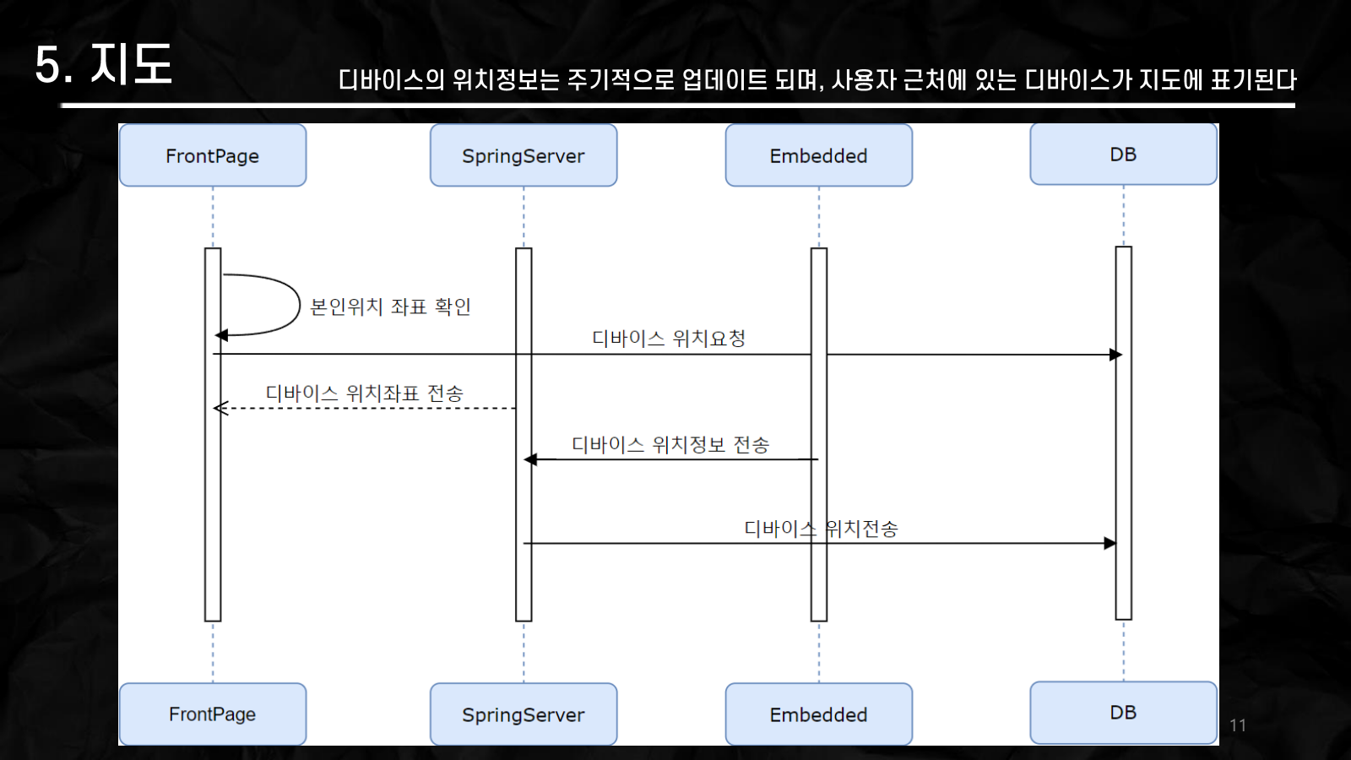
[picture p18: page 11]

7/31/2022 | 11 7/31/2022 | 11

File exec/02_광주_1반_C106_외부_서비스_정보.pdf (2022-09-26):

# 외부 서비스 정보

삼성SW청년아카데미 광주캠퍼스 7기
김도원 김강현 권덕민 윤성한 유승우 정혜원

## 1. Iamport

□ 사용 목적

ㅇ ssokdam 서비스 내에서 휴대폰 인증 및 계좌번호 인증을 위해 Iamport 서비스를 사용하였습니다.

□ 가입 및 활용

ㅇ 회원 가입 및 아이디 찾기, 비밀번호 찾기에서 활용됩니다 별도의 가입 절차는

## 없습니다. 2. 네이버 SENS

□ 사용 목적

ㅇ ssokdam 서비스 내에서 휴대폰 문자 인증 번호 시스템에서 사용하였습니다.

□ 가입 및 활용

ㅇ 아이디 찾기, 비밀번호 찾기에서 활용됩니다 별도의 가입 절차는 없습니다. 3. 카카오 MAP

□ 사용 목적

ㅇ ssokdam 서비스 내에서 임베디드 기기의 위치를 지도에 표시해주기 위해 사용하였습니다.

□ 가입 및 활용

ㅇ 지도 서비스 에서 활용됩니다 별도의 가입 절차는 없습니다. 4. 네이버 MAP

□ 사용 목적

ㅇ ssokdam 서비스 내에서 관리자 수거 시스템을 위해 사용하였습니다.

□ 가입 및 활용

ㅇ 관리자 수거 서비스 에서 활용됩니다 별도의 가입 절차는 없습니다.

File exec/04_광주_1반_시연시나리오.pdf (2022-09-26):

# Ssok Dam

### 공통 프로젝트 2022.07.04 ~ 2022.08.19 (7주)

### 광주 1반 6팀 C106 SSAFY 7th 김도원(팀장), 김강현, 권덕민, 윤성한, 유승우, 정혜원

### 담당 컨설턴트 - 실습코치 : 김동유 - 하현서

# 시연 시나리오

## [ 아이디 | 비밀번호 찾기 ]

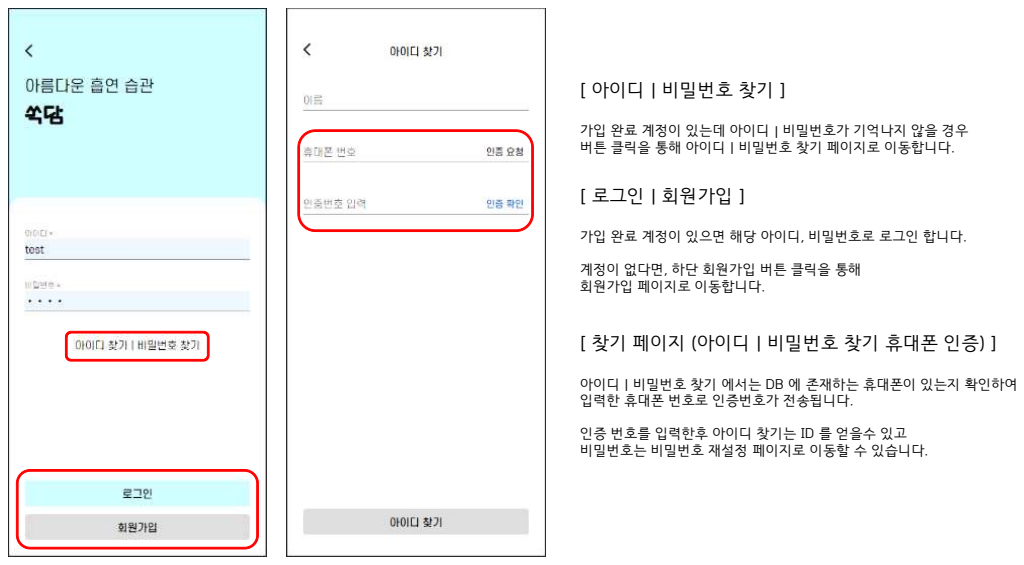
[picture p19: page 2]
[ 로그인 | 회원가입 ]

가입 완료 계정이 있는데 아이디 | 비밀번호가 기억나지 않을 경우
버튼 클릭을 통해 아이디 | 비밀번호 찾기 페이지로 이동합니다.

가입 완료 계정이 있으면 해당 아이디, 비밀번호로 로그인 합니다. 계정이 없다면, 하단 회원가입 버튼 클릭을 통해

회원가입 페이지로 이동합니다.

[ 찾기 페이지 (아이디 | 비밀번호 찾기 휴대폰 인증) ]

아이디 | 비밀번호 찾기 에서는 DB 에 존재하는 휴대폰이 있는지 확인하여
입력한 휴대폰 번호로 인증번호가 전송됩니다. 인증 번호를 입력한후 아이디 찾기는 ID 를 얻을수 있고

비밀번호는 비밀번호 재설정 페이지로 이동할 수 있습니다.

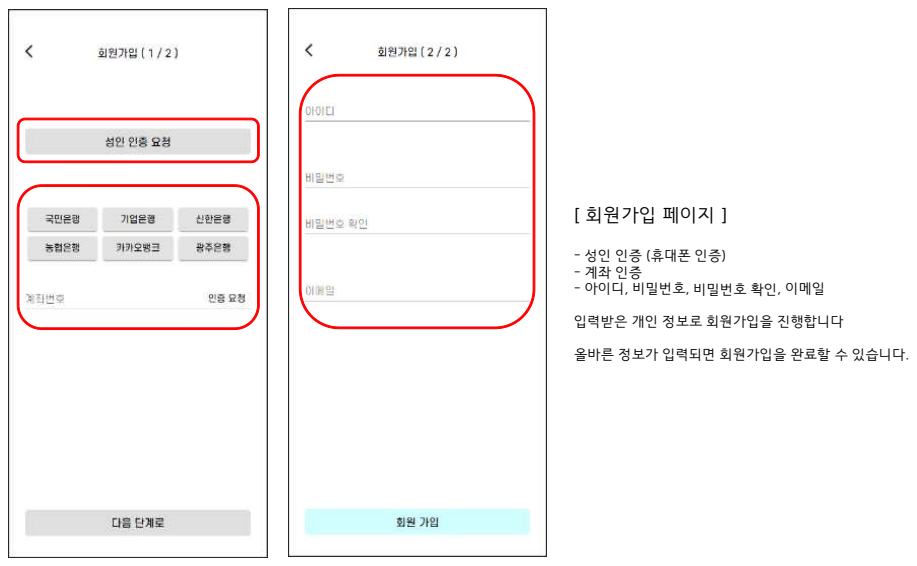
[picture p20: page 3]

[ 회원가입 페이지 ] - 성인 인증 (휴대폰 인증) - 계좌 인증

- 아이디, 비밀번호, 비밀번호 확인, 이메일

입력받은 개인 정보로 회원가입을 진행합니다

올바른 정보가 입력되면 회원가입을 완료할 수 있습니다.

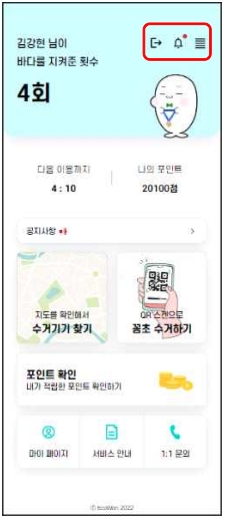
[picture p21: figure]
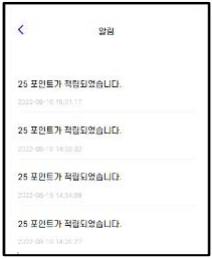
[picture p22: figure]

## [ 메인 Home 페이지 (상단 알람 버튼) ]

알람 버튼을 누르게되면 알람 페이지로 이동하게 되며 담배 포인트 적립 및 환전 했던 기록을 열람할 수 있습니다.

## [ 메인 Home 페이지 (상단 나가기 버튼) ]

로그인 이 되어 있을 경우 로그아웃이 되며, 로그아웃 상태에서 누를시 로그인 페이지로 이동하게 됩니다.

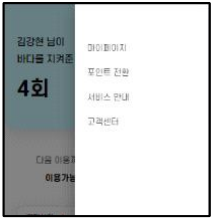
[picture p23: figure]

## [ 메인 Home 페이지 (상단 햄버거바) ]

마이페이지, 포인트 전환, 서비스 안내, 고객센터 메뉴를 오픈할 수 있습니다.

## [ 메인 Home 페이지 (횟수, 다음이용시간, 나의포인트) ]

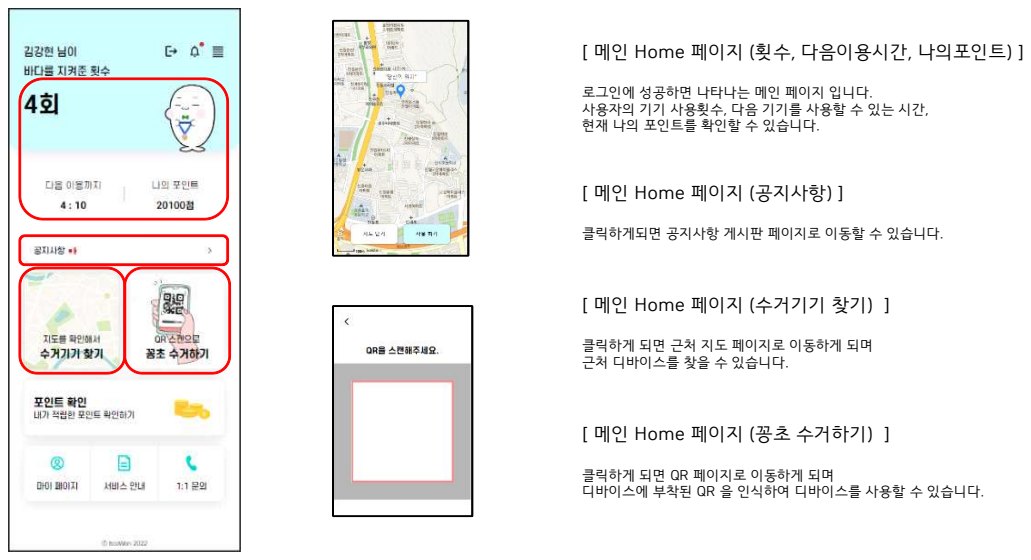
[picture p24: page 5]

로그인에 성공하면 나타나는 메인 페이지 입니다. 사용자의 기기 사용횟수, 다음 기기를 사용할 수 있는 시간, 현재 나의 포인트를 확인할 수 있습니다.

[ 메인 Home 페이지 (공지사항) ]

클릭하게되면 공지사항 게시판 페이지로 이동할 수 있습니다.

[ 메인 Home 페이지 (수거기기 찾기) ]

클릭하게 되면 근처 지도 페이지로 이동하게 되며
근처 디바이스를 찾을 수 있습니다.

[ 메인 Home 페이지 (꽁초 수거하기) ]

클릭하게 되면 QR 페이지로 이동하게 되며
디바이스에 부착된 QR 을 인식하여 디바이스를 사용할 수 있습니다.

## [ 메인 Home 페이지 (포인트 확인) ]

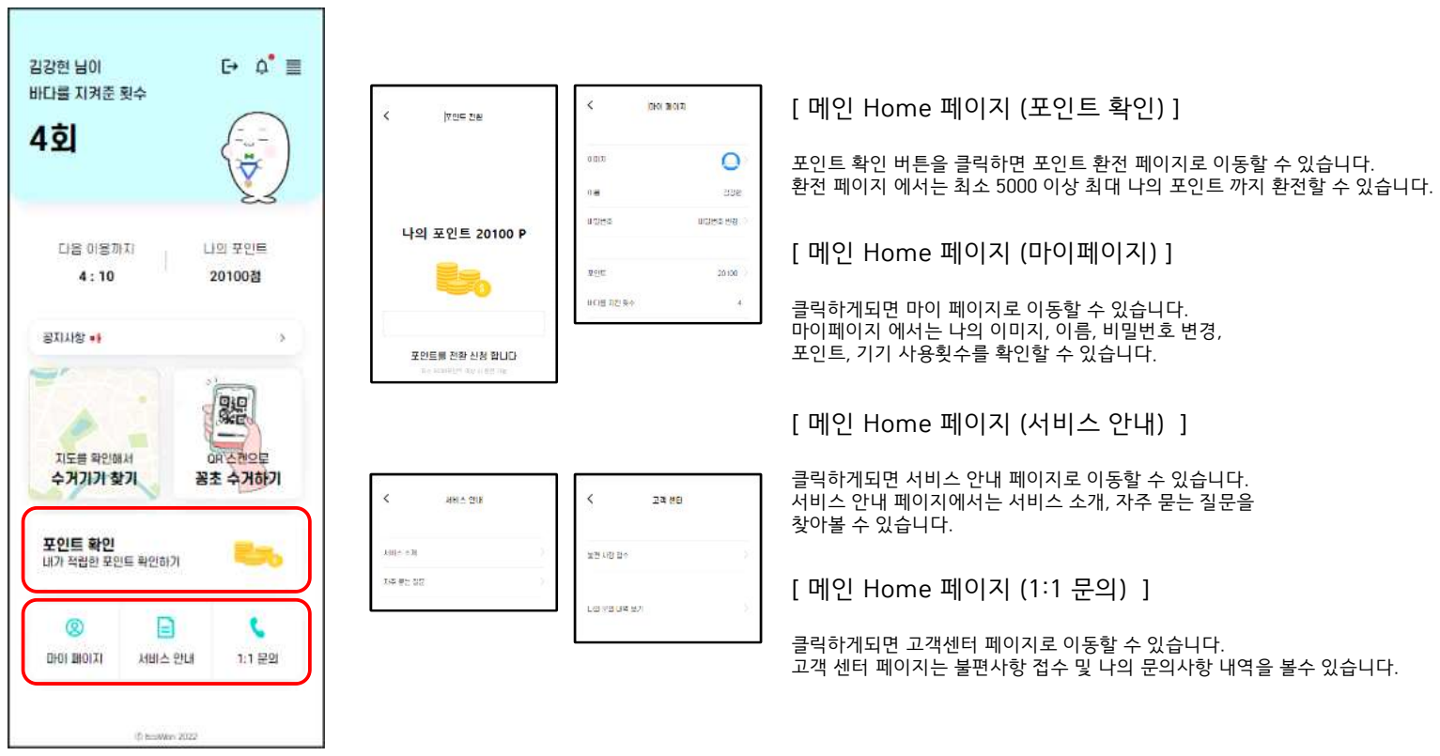
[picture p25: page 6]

## [ 메인 Home 페이지 (마이페이지) ]

클릭하게되면 마이 페이지로 이동할 수 있습니다. 마이페이지 에서는 나의 이미지, 이름, 비밀번호 변경, 포인트, 기기 사용횟수를 확인할 수 있습니다.

## [ 메인 Home 페이지 (서비스 안내) ]

클릭하게되면 서비스 안내 페이지로 이동할 수 있습니다. 서비스 안내 페이지에서는 서비스 소개, 자주 묻는 질문을

찾아볼 수 있습니다.

## [ 메인 Home 페이지 (1:1 문의) ]

클릭하게되면 고객센터 페이지로 이동할 수 있습니다. 고객 센터 페이지는 불편사항 접수 및 나의 문의사항 내역을 볼수 있습니다.

포인트 확인 버튼을 클릭하면 포인트 환전 페이지로 이동할 수 있습니다. 환전 페이지 에서는 최소 5000 이상 최대 나의 포인트 까지 환전할 수 있습니다.

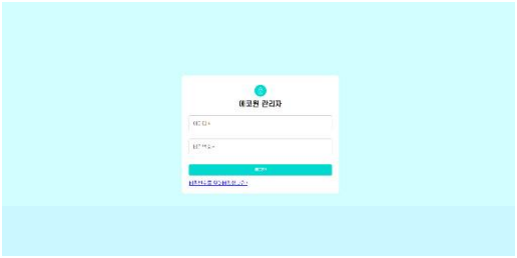
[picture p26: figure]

## [ 관리자 로그인 ]

가입 완료 계정이 있으면 해당 아이디, 비밀번호로 로그인 합니다. 비밀번호를 잊어버렸다면 하단의 찾기 버튼을 통해

비밀번호 찾기 페이지로 이동할 수 있습니다.


## [ 관리자 메인 페이지 ]

관리자 로그인이 성공하면 보여지는 페이지 입니다. - 지급요청, 지급된 금액, 회원 수

- 미처리 불만사항, 미처리 고장신고, 디바이스 알림, 문제 디바이스
- 최근 접수된 불만 사항
- 최근 접수된 고장 신고
와 같은 항목들을 한눈에 파악할 수 있습니다.


[ 관리자 기기 정보 확인 ]

관리자 기기 정보 확인 페이지 입니다. 지도 화면에서 디바이스 아이콘을 순서대로 클릭한후 길찾기 버튼을 누르면

해당 위치를 최단경로로 수거할수 있도록 표시할 수 있습니다. 현재 설치된 디바이스의 사용 횟수, 배터리양, 쓰레기통 양, 꽁초 양, 고장 여부

를 파악하여 알림이 필요한 디바이스는 노랑색 고장난 디바이스는 빨간색으로
표기하여 한눈에 파악할 수 있습니다.


[ 접수된 불만 사항 ]

관리자 접수된 불만 사항 페이지 입니다. 오른쪽 필터를 통하여 전체, 미처리, 처리 된 불만 사항을 볼수 있습니다. 해당 불만사항을 클릭하면 해당 게시판의 상세 내용 페이지로 이동하게 됩니다. 이동한 페이지에서는 답변, 삭제 기능을 수행할 수 있습니다.


[ 접수된 고장 사항 ]

관리자 접수된 고장 사항 페이지 입니다. 오른쪽 필터를 통하여 전체, 미처리, 처리 된 고장 사항을 볼수 있습니다. 해당 고장 사항을 클릭하면 해당 게시판의 상세 내용 페이지로 이동하게 됩니다. 이동한 페이지에서는 고장등록, 고장해제, 삭제, 답변 기능을 수행할 수 있습니다.


## [ 회원 관리 ]

관리자 회원 관리 페이지 입니다. 모든 회원의 정보를 한눈에 파악할수 있습니다. 특정회원의 삭제 기능또한 수행할 수 있습니다.


## [ 포인트 전환 ]

관리자 포인트 전환 페이지 입니다. 사용자가 요청한 포인트 전환 모든 항목을 확인 할수 있습니다

항목을 승인 또는 삭제하여 반려 시킬 수 있습니다.

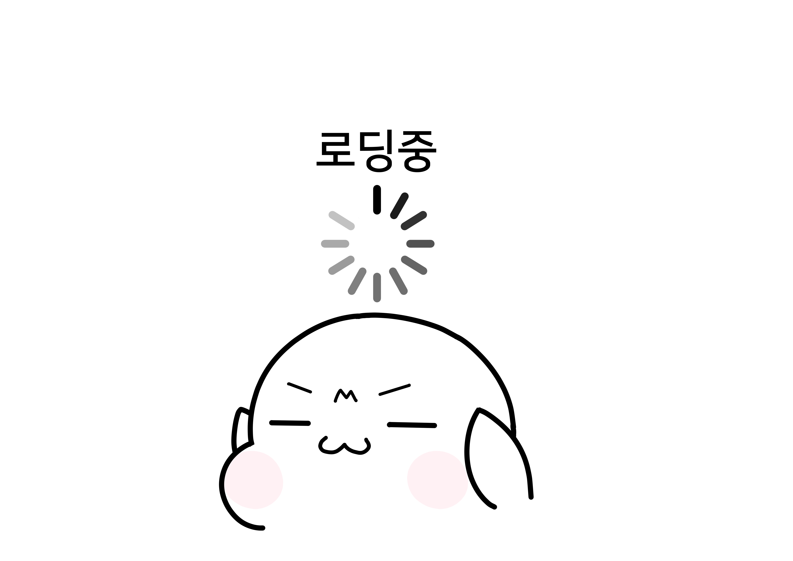
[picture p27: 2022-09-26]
Frontend/src/picture/loading_belu.gif

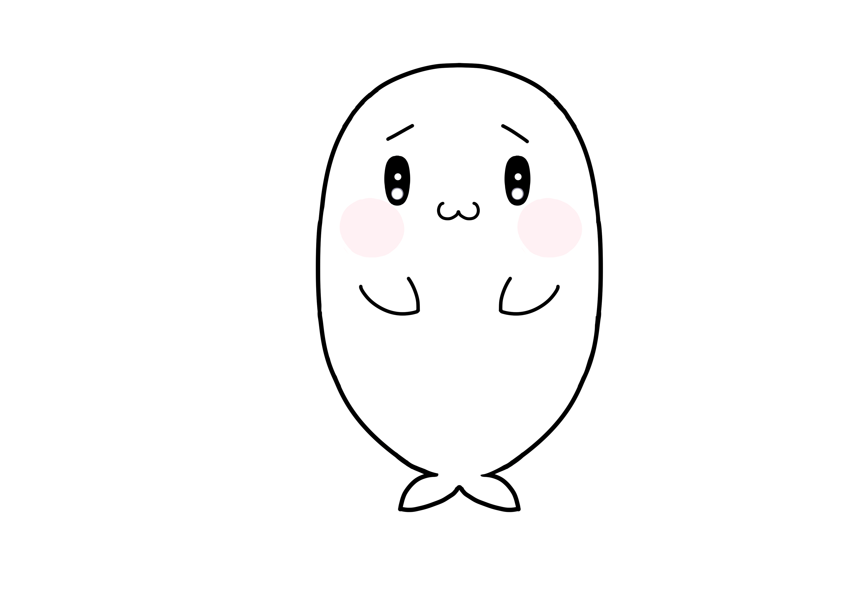
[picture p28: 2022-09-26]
Frontend/src/picture/main_belu.gif

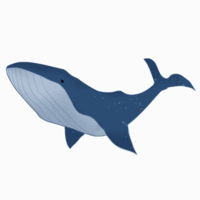
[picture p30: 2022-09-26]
Frontend/src/picture/moveWhale.gif

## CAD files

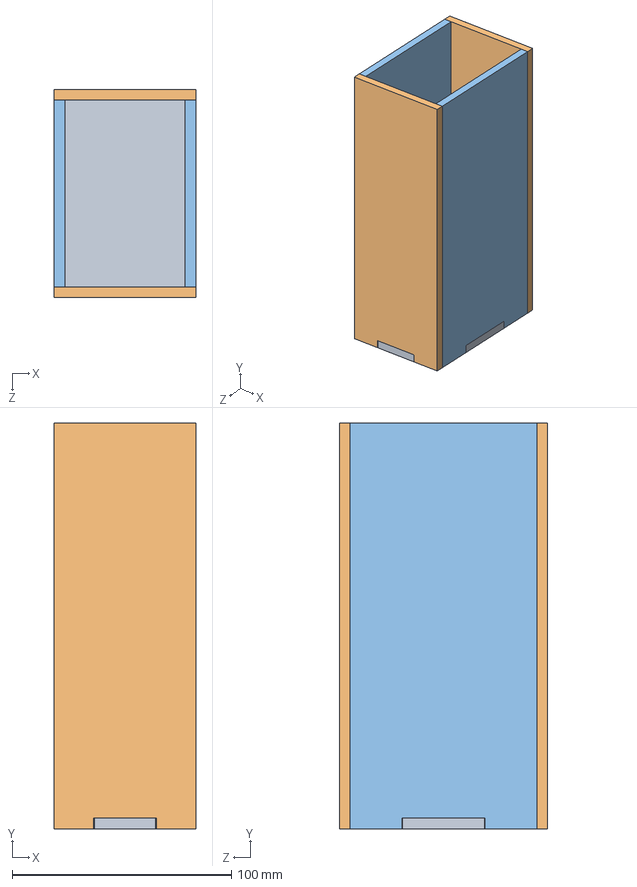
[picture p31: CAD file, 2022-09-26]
3D_Modelling/Body_2D/Cigbin/Cigbin_Assem.SLDASM
64.5 x 185.0 x 95.0 mm
Cigbin_Bottom
Cigbin_FrontBack x 2
Cigbin_Side x 2

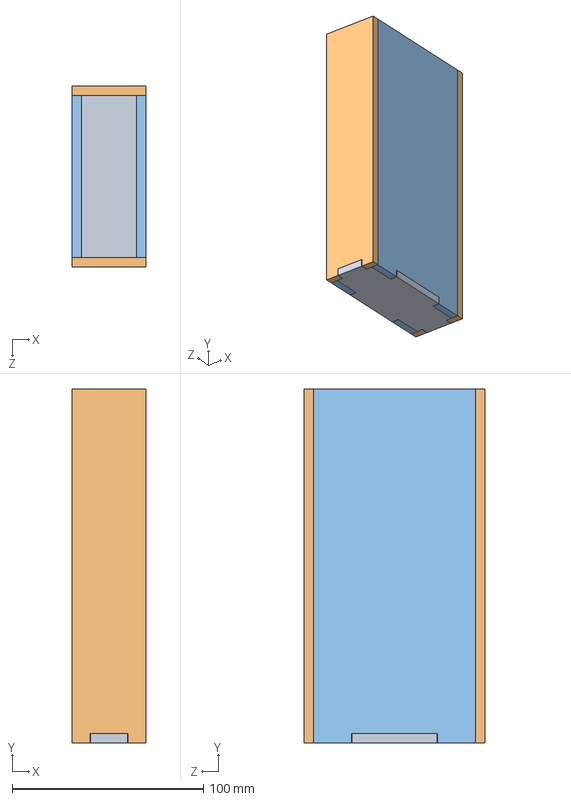
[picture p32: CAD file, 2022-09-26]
3D_Modelling/Body_2D/Trashbin/Trashbin_Assem.SLDASM
38.5 x 185.0 x 94.5 mm
Trashbin_Bottom
Trashbin_FrontBack x 2
Trashbin_Side x 2

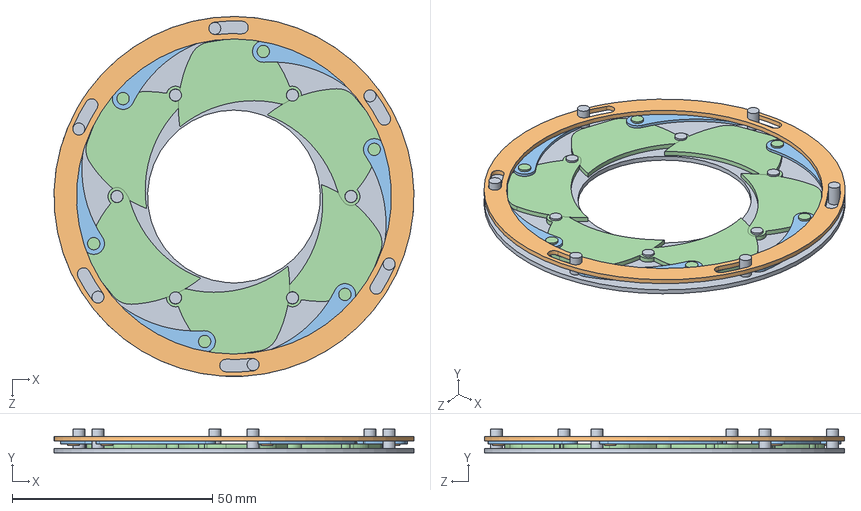
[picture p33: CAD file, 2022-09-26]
3D_Modelling/iris_Mechanism_r0/Iris Mechanism assembly.SLDASM
90.0 x 5.93 x 90.0 mm
1.Base
2. ring
3.balt x 6
4.Silder balt x 6

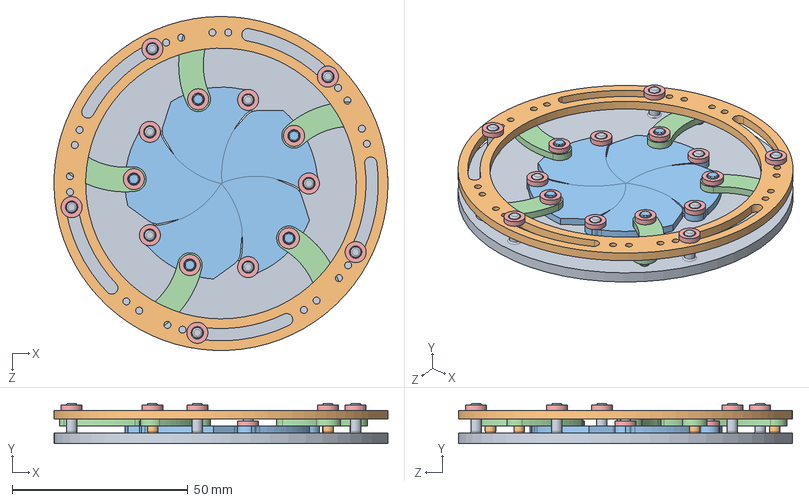
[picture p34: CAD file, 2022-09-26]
3D_Modelling/iris_Mechanism_r1/Iris_Mech.SLDASM
95.0 x 11.5 x 95.0 mm
1_Base
2_Ring
3_Slider x 5
4_Link x 5
5_Holder x 15

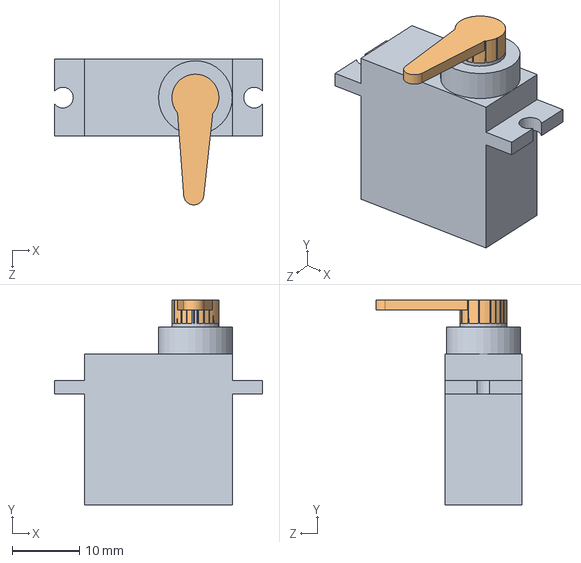
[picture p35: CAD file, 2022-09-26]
3D_Modelling/Motor/Servo_s.SLDASM
31.0 x 30.5 x 21.7 mm
Servo_s_Body
Servo_s_Wing

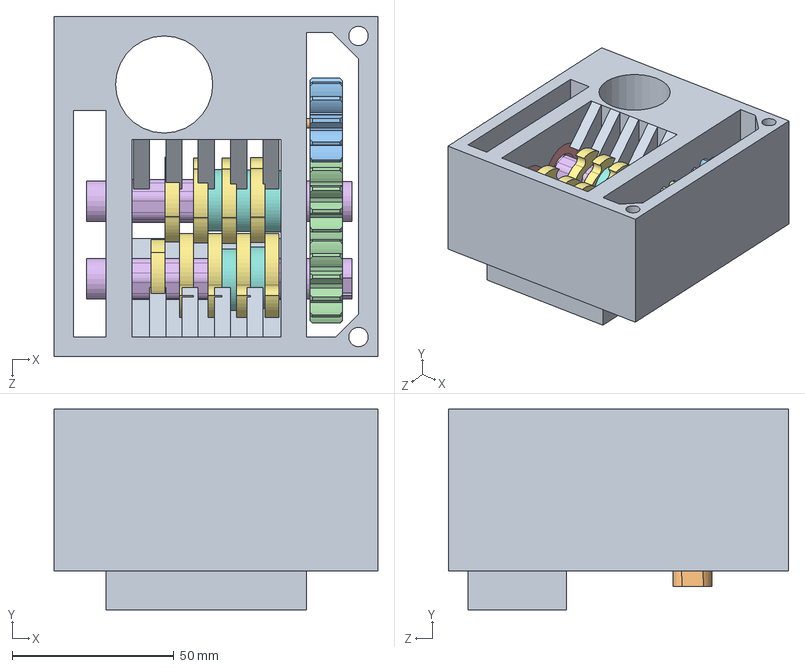
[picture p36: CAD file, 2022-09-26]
3D_Modelling/Shedder_Mechanism_r1/Shedder_Mech.SLDASM
100.0 x 62.0 x 105.0 mm
Shedder_body
DC
Spur_Power_M2Z12
Spur_Trans_M2Z24 x 2
Bearing x 4
Shaft x 2
Blade x 9
Spacer x 5
Shedder_cover

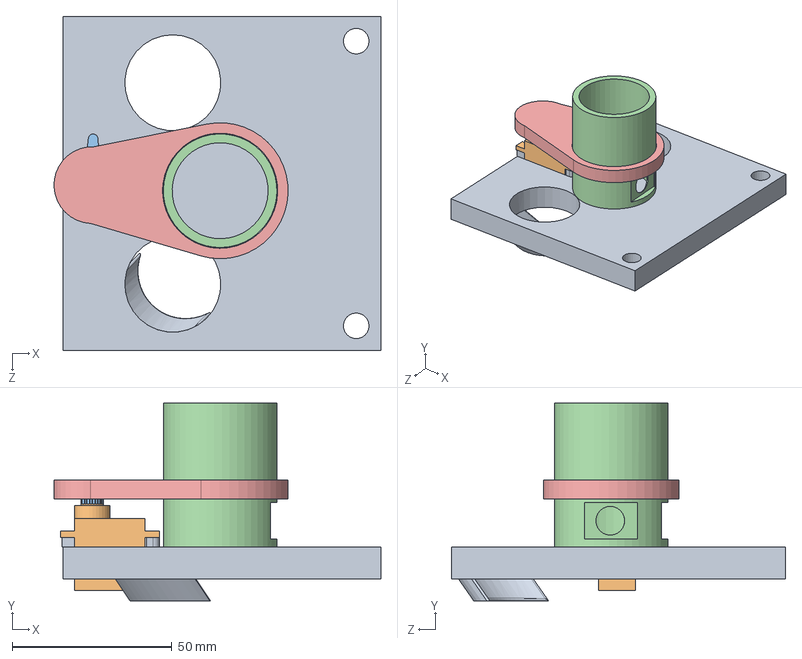
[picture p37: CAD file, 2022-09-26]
3D_Modelling/Slider2_Assem.SLDASM
102.2 x 61.8 x 104.5 mm
Slider_2
Servo_s_Body
Servo_s_Wing
Slider_2_Cover
ConnectingRod_2

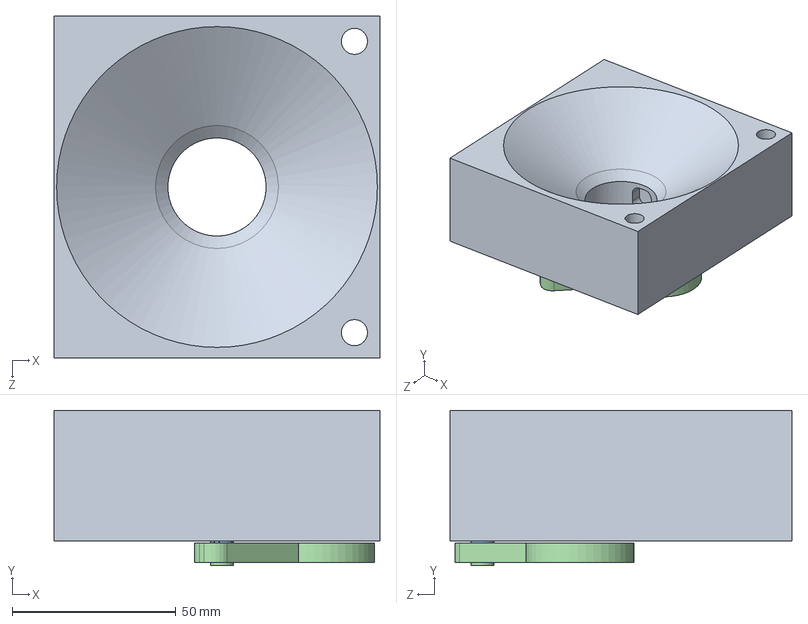
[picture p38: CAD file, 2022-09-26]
3D_Modelling/Slider1_Assem.SLDASM
99.5 x 47.5 x 104.5 mm
Slider_1
Servo_s_Body
Servo_s_Wing
ConnectingRod_1

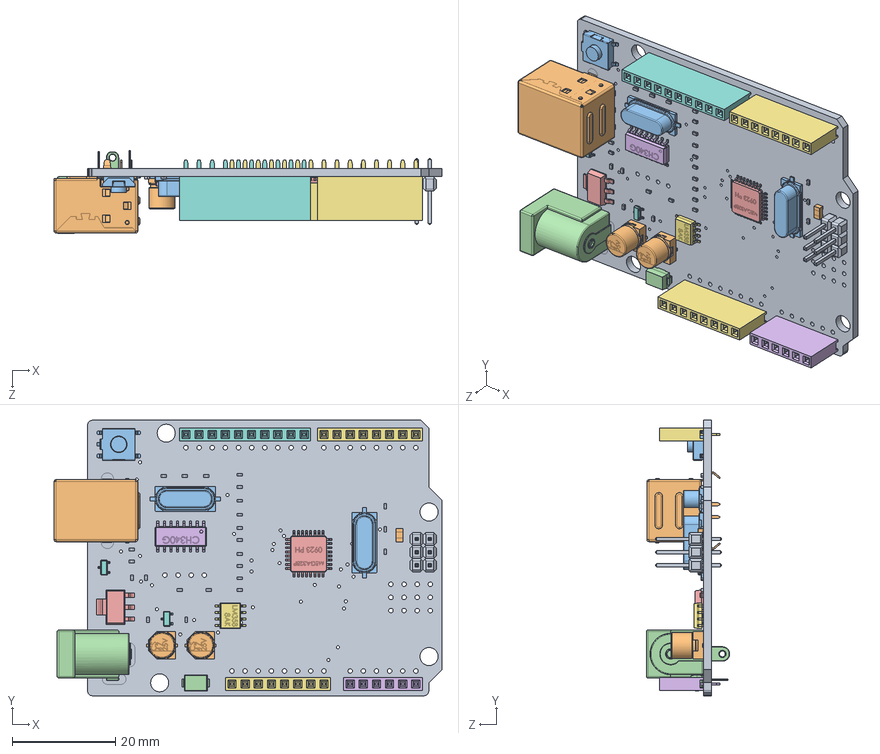
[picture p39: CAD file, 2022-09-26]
3D_Modelling/arduino-uno-r3/Assembly Arduino Uno R3.SLDASM
75.0 x 53.3 x 16.1 mm
1. Arduino uno PCB
2. USB
12. Button arduino
3. dc jack arduino
4. atmega 328p
2.0 header female 6
2.0 header female 8 x 2
2.0 header female 10
5. header male
10. cap arduino x 2
8. Arduino part 16MHZ x 2
6. diode
13. LM1117
14. Micro chip part Arduino
7.Lm358 arduino
11. Transistor x 2
9. part x 24
15. part 1

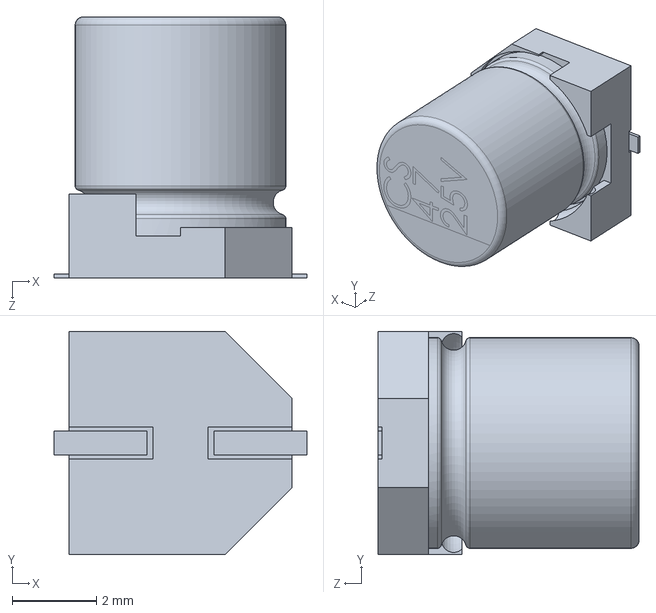
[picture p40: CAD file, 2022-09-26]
3D_Modelling/arduino-uno-r3/10. cap arduino.SLDPRT
6.00 x 5.30 x 6.20 mm

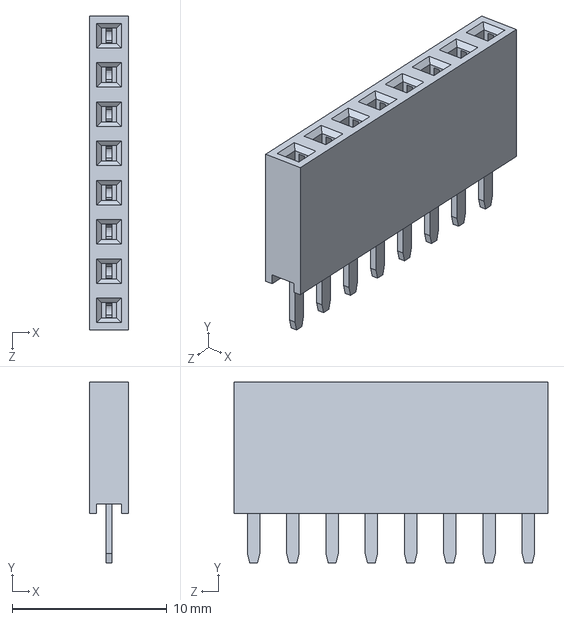
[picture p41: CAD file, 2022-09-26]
3D_Modelling/arduino-uno-r3/header female/2.0 header female 8.SLDPRT
2.54 x 11.7 x 20.3 mm

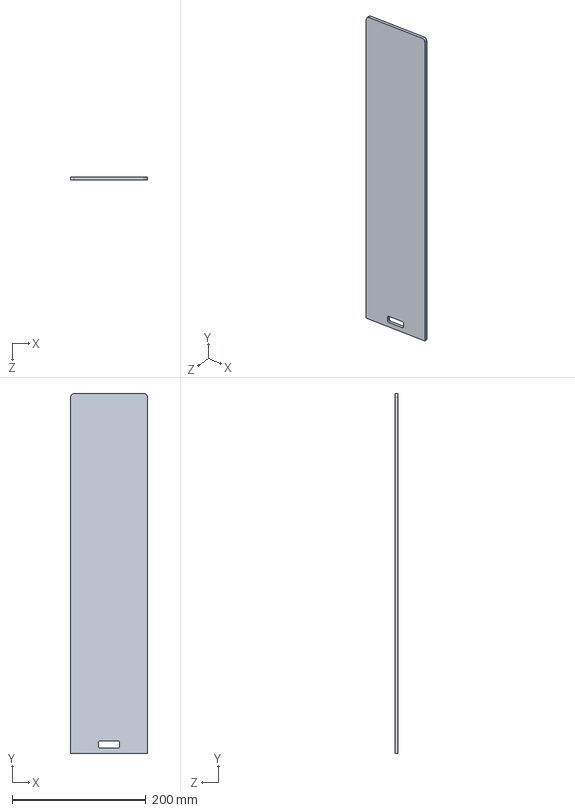
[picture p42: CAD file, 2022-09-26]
3D_Modelling/Body_2D/Body_Back.SLDPRT
115.0 x 539.2 x 5.00 mm

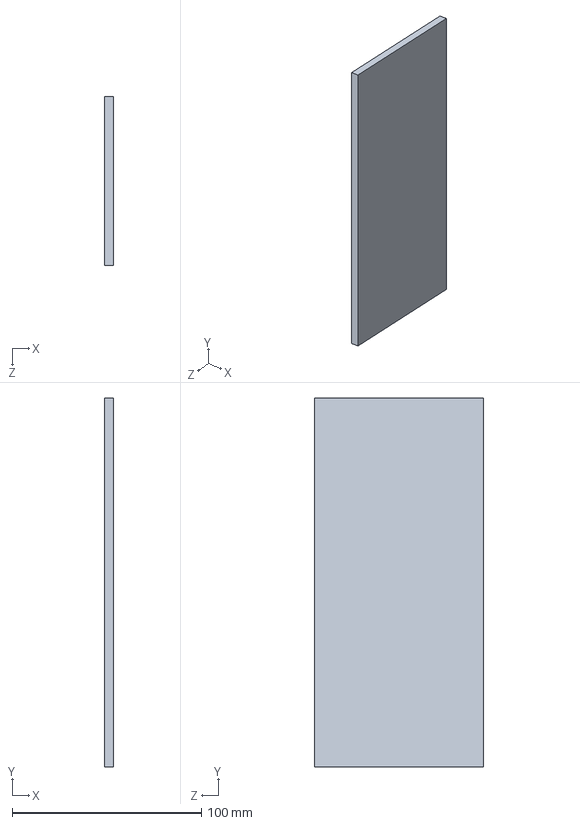
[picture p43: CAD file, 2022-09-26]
3D_Modelling/Body_2D/Cigbin/Cigbin_Side.SLDPRT
5.00 x 195.0 x 89.5 mm

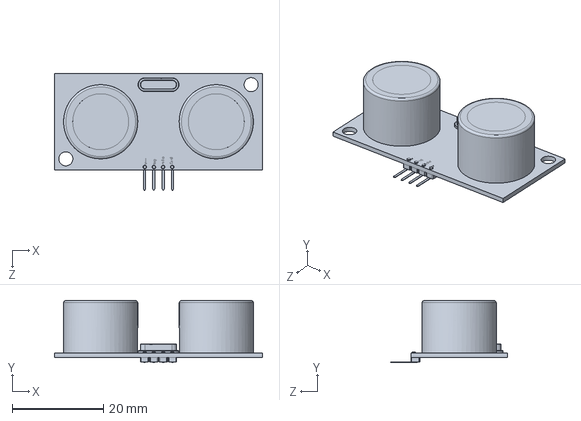
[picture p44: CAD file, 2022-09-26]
3D_Modelling/Body_2D/Sensor/HC-SR04 Ultrasonic sensor.SLDPRT
45.7 x 13.6 x 25.8 mm

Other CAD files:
3D_Modelling/Body_2D/Trashbin/Trashbin_Side.SLDPRT
3D_Modelling/ConnectingRod_2.SLDPRT
3D_Modelling/iris_Mechanism_r0/1.Base.SLDPRT
3D_Modelling/Battery_Pack.SLDPRT
3D_Modelling/Body.SLDPRT
3D_Modelling/Body_2D/Bin.SLDDRW
3D_Modelling/Body_2D/Body.SLDDRW
3D_Modelling/Body_2D/Body_Botton.SLDPRT
3D_Modelling/Body_2D/Body_Catch.SLDPRT
3D_Modelling/Body_2D/Body_Front.SLDPRT
3D_Modelling/Body_2D/Body_Side.SLDPRT
3D_Modelling/Body_2D/Body_Temp.SLDPRT
3D_Modelling/Body_2D/Body_Top.SLDPRT
3D_Modelling/Body_2D/Cigbin/Cigbin_Bottom.SLDPRT
3D_Modelling/Body_2D/Cigbin/Cigbin_FrontBack.SLDPRT
3D_Modelling/Body_2D/Trashbin/HC-SR04 Ultrasonic sensor.SLDPRT
3D_Modelling/Body_2D/Trashbin/Trashbin_Bottom.SLDPRT
3D_Modelling/Body_2D/Trashbin/Trashbin_FrontBack.SLDPRT
3D_Modelling/CigbuttBin.SLDPRT
3D_Modelling/ConnectingRod_1.SLDPRT
3D_Modelling/Motor/DC.SLDPRT
3D_Modelling/Motor/DC_L.SLDPRT
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

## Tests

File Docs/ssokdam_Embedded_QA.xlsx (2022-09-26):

대분류 |  | 중분류 |  | 소분류 |  | 전제조건 |  | 예상 결과 | 실제 결과 일치 여부
Setup | E-01 | WIFI 연결 | E-01-01 | WIFI 연결 | E-01-01-01 | WIFI가 정상적으로 공급 | E-01-01-01-01 | 콘솔에 와이파이 연결됨이 출력 | Y
Main_Process(Thread1) | E-02 | 개폐부 | E-02-01 | Json파싱 | E-02-01-01 | WIFI가 정상적으로 공급 | E-02-01-01-01 | 서버에 Get요청을 보내어 서버측으로 부터 key값에 맞는 JSON형식을 받아온다. | Y
 |  |  |  | input_open() | E-02-01-02 | ESP32의 ADC핀과 연결되어 전원이 공급 | E-02-01-02-01 | 담배 투입구가 열린다. | Y
 |  |  |  | input_close() | E-02-01-03 | ESP32의 ADC핀과 연결되어 전원이 공급 | E-02-01-03-01 | 담배 투입구가 닫힌다. | Y
 |  |  |  | cds() | E-02-01-04 | ESP32와 연결이 되어있는 상태 | E-02-01-04-01 | 빛반사을 감지하여 담배 통과를 인식한다. | Y
 |  | 판별부 | E-02-02 | 가스센서 | E-02-02-01 | ESP32의 ADC핀과 연결되어 전원이 공급 | E-02-02-01-01 | 일정 수준이상의 가스 감지 시 상태 변수를 담배인식으로 변경 | Y
 |  |  |  | 비접촉 온도센서 | E-02-02-02 | ESP32의 ADC핀과 연결되어 전원이 공급 | E-02-02-02-01 | 일정 온도 이상 시 상태 변수를 담배인식으로 변경 | Y
 |  |  |  | 미세먼지 센서 | E-02-02-03 | ESP32의 ADC핀과 연결되어 전원이 공급 | E-02-02-03-01 | 일정 수준이상의 미세먼지 검출 시 상태 변수를 담배인식으로 변경 | Y
 |  |  |  | returnPost() | E-02-02-04 | WIFI가 정상적으로 공급 | E-02-02-04-01 | userId와 userCheck를 JSON 형식으로 담아서 담배를 올바르게 투입했는지를 서버에 전달 | Y
 |  | 파쇄부 | E-02-03 | 파쇄 모터 | E-02-03-01 | 전원이 정상적으로 공급 | E-02-03-01-01 | 담배를 파쇄한다. | Y
 |  |  |  | 배터리잔량 체크 | E-02-03-02 | 전원이 정상적으로 공급 | E-02-03-02-01 | 배터리의 잔량을 embBat변수에 저장한다. | Y
Upload(Thread2) | E-03 | Post() | E-03-01 | embId 반환 | E-03-01-01 | WIFI가 정상적으로 공급 | E-03-01-01-01 | embId 값을 서버로 반환한다. | Y
 |  |  |  | userId 반환 | E-03-01-02 | WIFI가 정상적으로 공급 | E-03-01-02-01 | userId 값을 서버로 반환한다. | Y
 |  |  |  | embFullTra 반환 | E-03-01-03 | WIFI가 정상적으로 공급 | E-03-01-03-01 | embFullTra 값을 서버로 반환한다. | Y
 |  |  |  | embFullCig 반환 | E-03-01-04 | WIFI가 정상적으로 공급 | E-03-01-04-01 | embFullCig 값을 서버로 반환한다. | Y
 |  |  |  | embLat 반환 | E-03-01-05 | WIFI가 정상적으로 공급 | E-03-01-05-01 | embLat 값을 서버로 반환한다. | Y
 |  |  |  | embLng 반환 | E-03-01-06 | WIFI가 정상적으로 공급 | E-03-01-06-01 | embLng 값을 서버로 반환한다. | Y
 |  |  |  | embBat 반환 | E-03-01-07 | WIFI가 정상적으로 공급 | E-03-01-07-01 | embBat 값을 서버로 반환한다. | Y
 |  |  |  | embCnt 반환 | E-03-01-08 | WIFI가 정상적으로 공급 | E-03-01-08-01 | embCnt 값을 서버로 반환한다. | N
 |  |  |  | embSta 반환 | E-03-01-09 | WIFI가 정상적으로 공급 | E-03-01-09-01 | embSta 값을 서버로 반환한다. | N
 |  |  |  | embQr 반환 | E-03-01-10 | WIFI가 정상적으로 공급 | E-03-01-10-01 | embQr 값을 서버로 반환한다. | Y
 |  |  |  | embDummy 반환 | E-03-01-11 | WIFI가 정상적으로 공급 | E-03-01-11-01 | embDummy 값을 서버로 반환한다. | Y
 |  |  |  | https 연결 | E-03-01-12 | WIFI가 정상적으로 공급 | E-03-01-12-01 | https 보안프로토콜을 사용하여 서버측으로 전송 | Y

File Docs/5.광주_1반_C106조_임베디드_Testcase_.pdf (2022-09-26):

Testcase | 1

# Testcase

# 주요 기능 및 부품 테스트

No. | 주요 기능 | 부품 | 테스트 할 내용 | 수행절차 | 기대결과 | 수행결과
1 | 화재 감지 | 불꽃 감지 센서 SEN040132 | 화재가 발생 했을 경우 화재를 정확 히 감지 할 수있는 지 확인한다. | 1. 발화기구를 사 용하여 임의로 화 재유발 2. 감지 한 결과를 화면에서 확인 | 화재가 발생했을 시 정확히 감지 하 고 이를 서버 및 MCU에 전달. | 미수행
| 화재 감지 | 연기 감지 센서 HIS-07
2 | 화재 대비 | 워터 펌프 | 워터 펌프를 사용 하여 나온 물의 양 이 충분히 화재를 막을 수 있는지 확 인한다. | 1. 메인보드를 이 용하여 워터펌프 가동 2. 일정범위 에 물을 뿌려서 화 재진압 가능성 확 인 | 추가적으로 물뿌 리개 입구 모양 등 을 달아서 수압이 약하지만 넓은 범 위에 수분을 뿌려 화재 진압을 요함. | 미수행
3 | 절단 | 서보 모터 | 충분히 담배를 끊 어 낼 수 있는 힘 이 있는지 확인한 다. 모터에 칼날 등 날카로운 부품 을 달아서 자르기 용이하게 해본다. | 1. 메인보드를 통 해 서브모터 가동 2. 서브모터로 필 터를 절단이 가능 한지 확인 | 서보 모터를 가동 하여 필터부분과 담뱃잎 부분을 깔 끔히 절단. | 미수행
| 절단 | 스텝 모터 | 충분히 담배를 끊 어 낼 수 있는 힘 이 있는지 확인한 다. 모터에 칼날 등 날카로운 부품 을 달아서 자르기 용이하게 해본다. | 1. 메인보드를 통 해 스텝모터 가동 2. 스텝모터로 필 터를 절단이 가능 한지 확인 | 스텝 모터를 가동 하여 필터부분과 담뱃잎 부분을 깔 끔히 절단. | 미수행
4 | 담배꽁초 필터부 분을 구분 | 색인지 센서 Color Sensor TCS3200 | 담배 필터 부분의 경계를 잘 구분할 수 있는지 확인한 다. | 1. 메인보드를 사 용하여 센서 가동 2. 색인지 센서를 사용하여 구분 가 능성 확인 | 일정위치에서 필 터 경계부분을 판 별 시 MCU로 알 림 | 미수행
| 담배꽁초와 다른 이물질 판별 | 비접촉 적외선 온 도센서 TB-I2C-H04 | | 1. 메인보드를 사 용하여 센서 가동 2. 적외선 온도 센 서를 사용하여 구 분 가능성 확인 | 적정 온도가 아닌 담배일 경우 쓰레 기로 취급하고 MCU에 전달 및 수거 처리 | 미수행
5 | 담배 용량 측정 | 거리센서(초음파) | 쓰레기 통 내부의 쓰레기 부피(높이) 를 측정한다. (prototype의 경 우 50 cm까지 측 정가능해야한다.) | 1. 메인보드를 사 용하여 센서 가동 2. 거리 센서를 사 용하여 기능 확인 | 거리를 측정하여 현재 쓰래기통 내 부의 용량을 전송 (적절한 기준량 세 팅 요함) | 미수행

## Testcase

2

No. | 주 요 기 능 | 부 품 | 테 스 트 할 내 용 | 수 행 절 차 | 기 대 결 과 | 수 행 결 과
| 담 배 용 량 측 정 | 로 드 셀 | 쓰 레 기 통 내 부 의 쓰 레 기 무 게 를 측 정 | 1. 메 인 보 드 를 사 용 하 여 센 서 가 동 2. 거 리 센 서 를 사 용 하 여 기 능 확 인 | 무 게 를 측 정 하 여 현 재 쓰 래 기 통 내 부 의 용 량 을 전 송 ( 적 절 한 기 준 량 세 팅 요 함 ) | 미 수 행
6 | WIFI 연 결 | ESP8266 | 특 정 데 이 터 를 데 이 터 베 이 스 에 올 려 야 한 다 | 1. 메 인 보 드 와 ESP8266 모 듈 결 합 2. 서 버 와 통 신 이 잘 되 는 지 확 인 | 서 버 와 원 활 한 통 신 가 능 | 미 수 행

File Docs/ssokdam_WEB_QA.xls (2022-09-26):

No | 대분류 | 중분류 | 소분류 | 내용 | 추가내용 | 결과(1차/2차..) | 비고
1 | 사용자 기능 | 로그인/회원가입 화면 | 아이디 찾기 | 아이디 찾기 페이지 이동 |  | P
2 |  |  | 비밀번호 찾기 | 비밀번호 찾기 페이지 이동 |  | P
3 |  |  | 로그인 | 존재하지 않는 아이디 혹은 비밀번호 로그인 실패 확인 |  | P
4 |  |  |  | 존재하는 아이디, 비밀번호 로그인 성공 확인 |  | P
5 |  |  | 회원가입 | 회원가입 페이지 이동 |  | P
6 |  | 아아디 찾기 화면 | 이름 입력 | 휴대폰 번호에 맞는 사용자인지 확인하기 위한 이름 입력 공간 |  | P
7 |  |  | 휴대폰 번호 입력 / 인증 요청 버튼 | 입력된 휴대폰 번호에 ssokdam 인증번호 전송 |  | P
8 |  |  |  | ssokdam 에 존재하지 않는 휴대폰 번호 에러 메시지 출력 |  | P
9 |  |  | 인증번호 입력 / 인증 확인 버튼 | 올바른 인증번호 성공 확인 출력 |  | P
10 |  |  |  | 잘못된 인증번호 에러 메시지 출력 |  | P
11 |  |  | 아이디 찾기 버튼 | 인증 확인된 휴대폰 번호와 이름이 일치한 회원의 아이디 전송 |  | P
12 |  |  |  | 휴대폰 번호와 일치하지 않는 이름 에러 메시지출력 |  | P
13 |  | 비밀번호 찾기 화면 | 아이디 입력 | 휴대폰 번호에 맞는 사용자인지 확인하기 위한 아이디 입력 공간 |  | P
14 |  |  | 휴대폰 번호 입력 / 인증 요청 버튼 | 입력된 휴대폰 번호에 ssokdam 인증번호 전송 |  | P
15 |  |  |  | ssokdam 에 존재하지 않는 휴대폰 번호 에러 메시지 출력 |  | P
16 |  |  | 인증번호 입력 / 인증 확인 버튼 | 올바른 인증번호 성공 확인 출력 |  | P
17 |  |  |  | 잘못된 인증번호 에러 메시지 출력 |  | P
18 |  |  | 비밀번호 찾기 버튼 | 인증 확인된 휴대폰 번호와 아이디가 일치하면 비밀번호 변경 페이지 이동 |  | P
19 |  |  |  | 휴대폰 번호와 일치하지 않는 아이디 에러 메시지출력 |  | P
20 |  | 회원가입 화면 1 | 성인 인증 요청 | Iamport 핸드폰 인증 페이지 이동 |  | P
21 |  |  |  | 인증 페이지 오류시 에러 메시지 출력 |  | P
22 |  |  |  | 인증 성공시 성공 표시 확인 |  | P
23 |  |  | 은행 선택 버튼 | 버튼 선택 표시 확인 |  | P
24 |  |  | 계좌번호 입력 / 인증 요청 버튼 | 올바른 계좌번호 입력시 성공 출력 |  | P
25 |  |  |  | 틀린 계좌번호 입력시 에러 메시지 출력 |  | P
26 |  |  | 다음 단계로 | 올바른 정보 입력시 버튼 활성화 |  | P
27 |  |  |  | 잘못된 정보 입력시 버튼 비활성화 |  | P
28 |  | 회원가입 화면 2 | 아이디 | 플레이룸 이미지 클릭 시 플레이룸 화면 이동 확인 |  | P
29 |  |  | 비밀번호 / 비밀번호 확인 | 비밀번호 양식 일치시 경고 메시지 미출력 |  | P
30 |  |  |  | 비밀번호 양식 불일치 경고 메시지 출력 |  | P
31 |  |  |  | 비밀번호 확인, 비밀번호 일치 경고 메시지 미출력 |  | P
32 |  |  |  | 비밀번호 확인, 비밀번호 불일치 경고 메시지 출력 |  | P
33 |  |  | 이메일 | 이메일 양식 일치시 경고 메시지 미출력 |  | P
34 |  |  |  | 이메일 양식 불일치 경고 메시지 출력 |  | P
35 |  |  | 회원가입 버튼 | 잘못된 정보 입력시 에러 메시지 출력 |  | P
36 |  |  |  | 회원가입 성공 출력 |  | P
37 |  | 메인 화면 | 나가기 버튼 | 비로그인 상태에서 클릭 시 로그인 화면 이동 확인 |  | P
38 |  |  |  | 로그인 상태에서 클릭 시 비로그인 메인페이지 화면 이동 확인 |  | P
39 |  |  | 알람 버튼 | 클릭시 사용자의 포인트 적립 및 환전 내역 기록 화면 이동 확인 |  | P
40 |  |  | 햄버거바 | 비로그인 / 로그인 상태에서 클릭시 (마이페이지, 포인트 전환, 서비스 안내, 고객센터) 메뉴 표시 |  | P
41 |  |  | 다음 이용까지 | 최근 기기 사용시간 을 체크한 후 40분 체크 확인 |  | P
42 |  |  | 나의포인트 | 현재 사용자의 보유 포인트 확인 |  | P
43 |  |  | 공지사항 | 가장 최근 공지사항 Title 출력 확인 |  | P
44 |  |  |  | 클릭시 공지사항 게시판 화면 이동 |  | P
45 |  |  | 수거기기 찾기 | 비로그인 상태에서 사용하기 클릭시 로그인 화면 이동 |  | P
46 |  |  |  | 로그인 상태에서 클릭시 수거기기 찾기 페이지 화면 이동 |  | P
47 |  |  | 꽁초 수거하기 | 클릭시 QR 스캔 페이지 화면 이동 |  | P
48 |  |  | 포인트 환전 | 비로그인 상태에서 클릭시 로그인 화면 이동 |  | P
49 |  |  |  | 로그인 상태에서 클릭시 포인트 환전 페이지 이동 |  | P
50 |  |  | 마이페이지 | 비로그인 상태에서 클릭시 로그인 화면 이동 |  | P
51 |  |  |  | 로그인 상태에서 클릭시 마이페이지 화면으로 이동 |  | P
52 |  |  | 서비스 안내 | 서비스 안내 페이지 이동 |  | P
53 |  |  | 1 : 1 문의 | 고객 센터 페이지 이동 |  | P
54 |  | 알림 화면 | 화면 표시 | 사용자가 적립한 포인트, 환전 기록 표시 확인 |  | P
55 |  | 마이페이지 화면 | 이미지 | 사용자의 이미지 표시 확인 | 이미지 필드 추가 필요 | F / P
56 |  |  | 아이디 | 사용자의 아이디 확인 |  | P
57 |  |  | 비밀번호 / 비밀번호 변경 | 비밀번호 변경 버튼 클릭시 비밀번호 변경 페이지 이동 확인 |  | P
58 |  |  | 포인트 | 사용자의 포인트 일치 확인 |  | P
59 |  |  |  | 사용자의 포인트 클릭시 전환 페이지 이동 확인 |  | P
60 |  |  | 바다를 지킨 횟수 | 사용자의 담배 cnt 일치 확인 |  | P
61 |  | 포인트 전환 화면 | 나의 포인트 | 사용자의 포인트 일치 확인 |  | P
62 |  |  | 전환신청 버튼 | 5000 이하 포인트 입력시 에러 메시지 출력 |  | P
63 |  |  |  | 보유포인트 초과 입력시 에러 메시지 출력 |  | P
64 |  |  |  | 올바른 정보 입력시 성공 메시지 출력 |  | P
65 |  |  |  | 성공 메시지 출력후 메인페이지 이동 확인 |  | P
66 |  | 서비스 안내 화면 | 서비스 소개 | 서비스 소개 페이지 이동 확인 | 내용 보충 필요 | F / P
67 |  |  | 자주 묻는 질문 | 자주 묻는 질문 페이지 이동 확인 | 내용 보충 필요 | F / P
68 |  | 서비스 소개 화면 | 화면 출력 | 화면 출력 확인 | 내용 보충 필요 | F / P
69 |  | 자주 묻는 질문 화면 | 화면 출력 / 클릭 | 자주 묻는 질문 클릭시 페이지 이동 확인 | 내용 보충 필요 | F / P
70 |  | 고객센터 | 불편 사항 접수 | 불편사항 접수 페이지 이동 확인 |  | P
71 |  |  | 나의 문의 내역 | 나의 문의 내역 페이지 이동 확인 |  | P
72 |  | 불편사항 접수 화면 | 문의 유형 | 불편사항 및 고장신고 선택 화면 표시 |  | P
73 |  |  |  | 고장신고 선택시 고장기기 등록 QR 버튼 표시 확인 |  | P
74 |  |  |  | 불편사항 선택시 고장기기 등록 QR 버튼 없는지 확인 |  | P
75 |  |  | 제목 | 문의 유형 제목 입력란 확인 |  | P
76 |  |  | 내용 | 문의 유형 내용 입력란 확인 |  | P
77 |  |  | 파일 | 파일 클릭시 파일 업로드 화면 출력 확인 |  | P | 자문
78 |  |  |  | 이미지 업로드시 화면에 출력 확인 |  | P
79 |  |  | 제출하기 | 올바른 정보 입력시 버튼 활성화 |  | P
80 |  |  |  | 잘못된 정보 입력시 버튼 비활성화 |  | P
81 |  |  |  | 버튼 클릭시 성공 메시지 출력 확인 |  | P
82 |  |  |  | 출력 확인후 나의 문의 내역 화면 이동 확인 |  | P
83 |  | 나의 문의 내역 화면 | 화면 표시 | 사용자가 작성한 문의 내역 확인 |  | P
84 |  | 공지사항 화면 | 화면 표시 | 관리자가 작성한 공지사항 확인 |  | P
85 |  | 수거기기 찾기 화면 | 화면 표시 | 현재 나의 위치 확인 |  | P
86 |  |  |  | 설치된 기기의 위치 확인 |  | P
87 |  |  | 지도 닫기 | 버큰 클릭시 메인 페이지 이동 확인 |  | P
88 |  |  | 기기 사용 | QR 스캔 페이지 이동 확인 |  | P
89 |  | 꽁초 수거하기 화면 | 화면 표시 | QR 스캔 작동 확인 |  | P
90 |  |  | QR 스캔 | 올바른 QR 스캔시 로딩중 페이지 화면 이동 확인 |  | P
91 |  |  |  | Embedded 태이블 확인 |  | P
92 |  |  |  | 잘못된 QR 스캔시 에러 메시지출력 |  | F / P
93 |  | 로딩중 페이지 화면 | 화면 표시 | 담배꽁초 "Y" 일시 성공 메시지 출력 확인 |  | P
94 |  |  |  | 담배꽁초 "N" 일시 에러 메시지 출력 확인 |  | P
95 |  |  |  | 담배꽁초 "X" 일시 에러메시지 출력 확인 |  | P
96 |  |  |  | 담배꽁초 "P" 일시 로딩 페이지 계속 출력 확인 |  | P
97 | 관리자 기능 | 관리자 메인 | 지급 요청 | 현재 지급되지 않은 환전 갯수 확인 |  | P
98 |  |  |  | 클릭시 포인트 전환 페이지 이동 확인 |  | P
99 |  |  | 지급된 금액 | 현재까지 지급된 포인트 금액 확인 |  | P
100 |  |  |  | 클릭시 지급된 포인트 전환 페이지 이동 확인 |  | P
101 |  |  | 회원수 | 현재 ssokdam 을 사용중인 회원수 확인 |  | P
102 |  |  | 미처리 불만사항 | 처리되지 않은 불만사항 갯수 확인 |  | P
103 |  |  |  | 클릭시 접수된 불만사항 페이지 이동 확인 |  | P
104 |  |  | 미처리 고장신고 | 처리되지 않은 고장신고 갯수 확인 |  | P
105 |  |  |  | 클릭시 접수된 고장신고 페이지 이동 확인 |  | P
106 |  |  | 디바이스 알림 | 현재 관리가 필요한 디바이스 갯수 확인 |  | P
107 |  |  |  | 클릭시 현재 기기 정보 페이지 이동 확인 |  | P
108 |  |  | 문제 디바이스 | 현재 고장난 디바이스 갯수 확인 |  | P
109 |  |  |  | 클릭시 현재 기기 정보 페이지 이동 확인 |  | P
110 |  |  | 접수된 불만사항 | 최근 접수된 불만사항 top3 확인 | 역순 정렬 필요 | F / P
111 |  |  |  | 클릭시 접수된 불만사항 페이지 이동 확인 |  | P
112 |  |  | 접수된 고장신고 | 최근 접수된 고장신고 top3 확인 | 역순 정렬 필요 | F / P
113 |  |  |  | 클릭시 접수된 고장신고 페이지 이동 확인 |  | P
114 |  | 공지사항 관리 화면 | 화면 표시 | 현재 등록된 모든 공지사항 표시 확인 |  | P
115 |  |  |  | 클릭시 공지사항 상세 페이지 이동 확인 |  | P
116 |  | 공지사항 상세 화면 | 화면표시 | 상세 공지사항의 제목, 내용, 이미지 확인 |  | P
117 |  |  | 수정하기 | 클릭시 수정 페이지 이동 확인 |  | P
118 |  |  |  | 내용 수정후 수정 클릭시 데이터 수정 확인 |  | P
119 |  |  | 삭제 | 클릭시 삭제 확인 |  | P
120 |  | 기기 정보 확인 | 길찾기 | 클릭시 지도에서 선택된 위치를 기반으로 네이버 길찾기 페이지 이동 확인 |  | P
121 |  |  | 로드뷰 | 클릭시 지도화면이 로드뷰 바뀌는것 확인 |  | P
122 |  |  | 교통정보 보기 | 현재 지도에서 교통정보 표시 확인 |  | P
123 |  |  | 로드뷰 도로정보 보기 | 현재 지도에서 로드뷰 도로정보 표시 확인 |  | P
124 |  |  | 지형정보 보기 | 현재 지도에서 지형정보 표시 확인 |  | P
125 |  |  | 지적편집도 보기 | 현재 지도에서 지적편집도 표시 확인 |  | P
126 |  |  | 경로 초기화 | 지도에서 선택된 경유지 모두 초기화 되는지 확인 |  | P
127 |  |  | 경로한칸뒤로 | 지도에서 선택된 경유지 마지막 초기화 되는지 확인 |  | P
128 |  |  | 고장상태 변경 | 선택된 디바이스 고장여부 바뀌는지 확인 |  | P
129 |  | 네이버 길찾기 화면 | 화면 표시 | 선택된 디바이스 를 경유지로 현재 내위치에서 가장 빠른 경로 표시되는지 확인 |  | P
130 |  | 접수된 불만 사항 화면 | 화면 표시 | 미처리된 모든 불만사항 표시 확인 |  | P
131 |  |  |  | 클릭시 불만사항 상세 페이지 이동 확인 |  | P
132 |  |  | 필터 | 미처리 / 처리 / 전체 를 필터하수 있는 기능 확인 |  | P
133 |  |  |  | 필터 클릭시 필터된 데이터 맞는지 확인 |  | P
134 |  | 불만사항 상세 화면 | 삭제 | 클릭시 작성된 게시판 삭제되는지 확인 |  | P
135 |  |  | 댓글 작성 | 클릭시 작성된 댓글 확인 |  | P
136 |  |  |  | 작성된 불만사항 답변여부 'Y' 로 확인 |  | P
137 |  | 접수된 고장 신고 화면 | 화면 표시 | 미처리된 모든 불만사항 표시 확인 |  | P
138 |  |  |  | 클릭시 불만사항 상세 페이지 이동 확인 |  | P
139 |  |  | 필터 | 미처리 / 처리 / 전체 를 필터하수 있는 기능 확인 |  | P
140 |  |  |  | 필터 클릭시 필터된 데이터 맞는지 확인 |  | P
141 |  | 고장신고 상세 화면 | 삭제 | 클릭시 작성된 게시판 삭제되는지 확인 |  | P
142 |  |  | 댓글 작성 | 클릭시 작성된 댓글 확인 |  | P
143 |  |  |  | 작성된 불만사항 답변여부 'Y' 로 확인 |  | P
144 |  |  | 고장등록 | 클릭시 입력된 디바이스 고장 체크 확인 |  | P
145 |  |  |  | 클릭시 고장등록 버튼 고장해제 버튼으로 바귀는지 확인 |  | P
146 |  | 회원 관리 | 화면 표시 | 모든 회원 표시 확인 |  | P
147 |  |  | 삭제 | 선택된 회원 삭제되는지 확인 |  | P
148 |  | 포인트 전환 화면 | 화면 표시 | 처리되지 않은 포인트 전환 항목 표시 확인 |  | P
149 |  |  | 승인 | 선택한 환전 항목 승인 처리 확인 |  | P
150 |  |  | 삭제 | 선택한 환전 항목 삭제 처리 확인 |  | P

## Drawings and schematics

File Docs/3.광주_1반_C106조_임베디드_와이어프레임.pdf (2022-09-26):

# 에코 원

# 담배꽁초 처리 흐름도

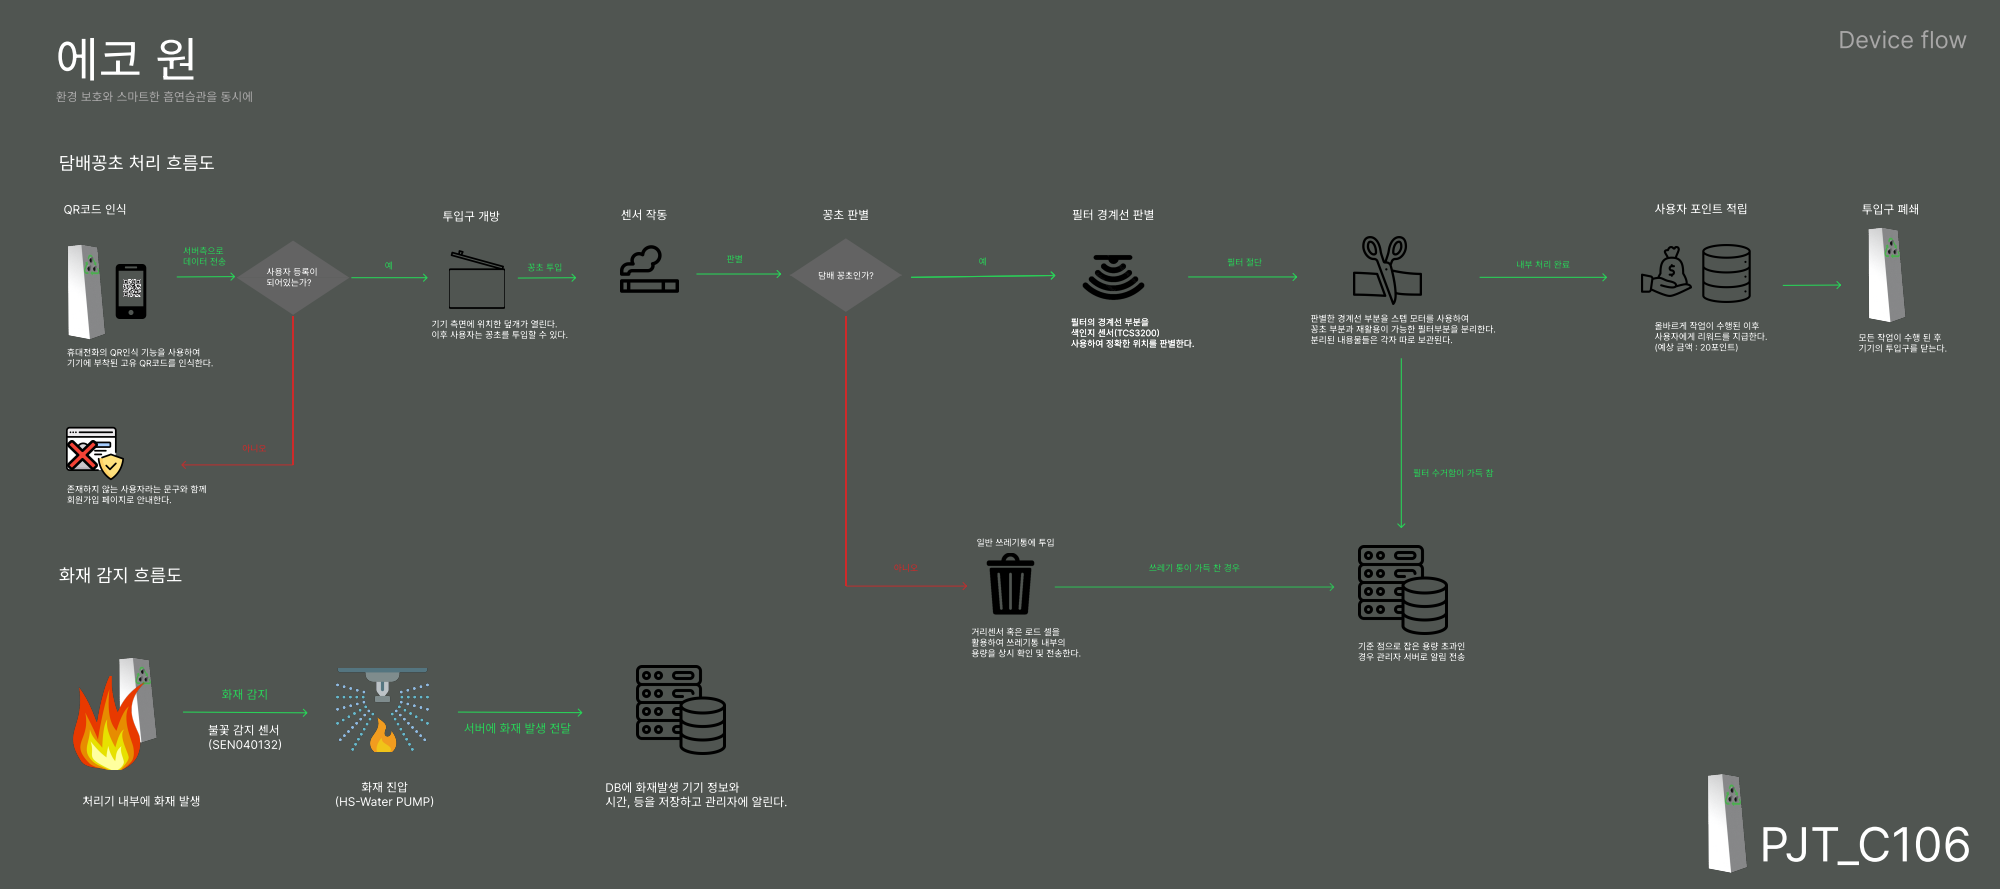
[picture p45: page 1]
투입구 개방 QR코드 인식; 투입구 폐쇄; 서버측으로 데이터 전송; 아니오; 쓰레기 통이 가득 찬 경우; 용량을 상시 확인 및 전송한다.; 기준 점으로 잡은 용량 초과인; 필터 경계선 판별; 사용자 포인트 적립; Device flow; 처리기 내부에 화재 발생; 시간, 등을 저장하고 관리자에 알린다.; 사용자 등록이; 되어있는가?; 담배 꽁초인가?; PJT_C106

환경 보호와 스마트한 흡연습관을 동시에

판별한 경계선 부분을 스텝 모터를 사용하여
꽁초 부분과 재활용이 가능한 필터부분을 분리한다.
분리된 내용물들은 각자 따로 보관된다.

기기 측면에 위치한 덮개가 열린다.
이후 사용자는 꽁초를 투입할 수 있다.

필터의 경계선 부분을
색인지 센서(TCS3200)
사용하여 정확한 위치를 판별한다.

올바르게 작업이 수행된 이후
사용자에게 리워드를 지급한다.
(예상 금액 : 20포인트)

모든 작업이 수행 된 후
기기의 투입구를 닫는다.

휴대전화의 QR인식 기능을 사용하여
기기에 부착된 고유 QR코드를 인식한다.

필터 수거함이 가득 참

존재하지 않는 사용자라는 문구와 함께
회원가입 페이지로 안내한다.

일반 쓰레기통에 투입

화재 감지 흐름도

거리센서 혹은 로드 셀을
활용하여 쓰레기통 내부의

경우 관리자 서버로 알림 전송

서버에 화재 발생 전달

(SEN040132)

(HS-Water PUMP)

DB에 화재발생 기기 정보와

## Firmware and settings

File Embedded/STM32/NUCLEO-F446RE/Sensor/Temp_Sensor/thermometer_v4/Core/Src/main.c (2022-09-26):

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
/* Includes ------------------------------------------------------------------*/
#include "main.h"

/* USER CODE BEGIN Includes */
#include <stdio.h>
#include <math.h>
/* USER CODE END Includes */

/* USER CODE BEGIN PD */
#define MLX90614_addr 0x5A
#define mlx_cmd_pointer 1
#define mlx_cmd_amb 0x06
#define mlx_cmd_obj_1 0x07
#define mlx_cmd_obj_2 0x08
#define mlx_cmd_emissivity 0x24
#define mlx_cmd_emissivity_2 0x2F
/* USER CODE END PD */

I2C_HandleTypeDef hi2c1;

UART_HandleTypeDef huart2;

/* USER CODE BEGIN PV */
uint8_t mlx_read_buffer[6]={0xB4,0x00,0xB5,0};
uint8_t mlx_write_buffer[5]={0xB4,0};
uint8_t mlx_write_zero[5]={0xB4,0};
char uart_buf[30];
/* USER CODE END PV */

void SystemClock_Config(void);
static void MX_GPIO_Init(void);
static void MX_I2C1_Init(void);
static void MX_USART2_UART_Init(void);
/* USER CODE BEGIN 0 */
void mlx_read_temperature(void)
{
	double temp_obj_1, temp_obj_2, temp_amb;
	mlx_read_buffer[mlx_cmd_pointer]=mlx_cmd_amb;

	HAL_I2C_Mem_Read_IT(&hi2c1,(uint16_t)MLX90614_addr<<1,mlx_cmd_amb,I2C_MEMADD_SIZE_8BIT,
			(uint8_t *)&mlx_read_buffer[3],3);

	while(HAL_I2C_GetState(&hi2c1)!=HAL_I2C_STATE_READY)
	{

	}
	temp_amb=(mlx_read_buffer[4]<<8|mlx_read_buffer[3]);
	temp_amb=(temp_amb*0.02)-273.15;

	memset(uart_buf,0,30);
	sprintf(uart_buf, "amb : %.2lf\n\r", temp_amb);
	HAL_UART_Transmit_IT(&huart2, uart_buf, sizeof(uart_buf));

	mlx_read_buffer[mlx_cmd_pointer]=mlx_cmd_obj_1;
	HAL_I2C_Mem_Read_IT(&hi2c1,(uint16_t)MLX90614_addr<<1,mlx_cmd_obj_1,I2C_MEMADD_SIZE_8BIT,
    	(uint8_t *)&mlx_read_buffer[3],3);
	while(HAL_I2C_GetState(&hi2c1)!=HAL_I2C_STATE_READY)
	{

	}
	temp_obj_1=(mlx_read_buffer[4]<<8|mlx_read_buffer[3]);
	temp_obj_1=(temp_obj_1*0.02)-273.15;

	memset(uart_buf,0,30);
	sprintf(uart_buf, "obj1 : %.2lf\n\r", temp_obj_1);
	HAL_UART_Transmit_IT(&huart2, uart_buf, sizeof(uart_buf));

	/*
	Object 2 temperature, RAM-0x07
	*/
	mlx_read_buffer[mlx_cmd_pointer]=mlx_cmd_obj_2;
	HAL_I2C_Mem_Read_IT(&hi2c1,(uint16_t)MLX90614_addr<<1,mlx_cmd_obj_2,I2C_MEMADD_SIZE_8BIT,
    	(uint8_t *)&mlx_read_buffer[3],3);
	while(HAL_I2C_GetState(&hi2c1)!=HAL_I2C_STATE_READY)
	{

	}
	temp_obj_2=(mlx_read_buffer[4]<<8|mlx_read_buffer[3]);
	temp_obj_2=(temp_obj_2*0.02)-273.15;

	memset(uart_buf,0,30);
	sprintf(uart_buf, "obj2 : %.2lf\n\r", temp_obj_2);
	HAL_UART_Transmit_IT(&huart2, uart_buf, sizeof(uart_buf));
}

void mlx_sleep()
{
	uint8_t enter_sleep[2]={0xFF,0xE8};	//0xFF-Sleep CMD, 0xE8-PEC (0xB4+0xFF)
	HAL_I2C_Master_Transmit_IT(&hi2c1,(uint16_t)MLX90614_addr<<1,(uint8_t *)&enter_sleep,2);
	while(HAL_I2C_GetState(&hi2c1)!=HAL_I2C_STATE_READY)
	{
	}
}

void mlx_wakeup()
{

	HAL_I2C_DeInit(&hi2c1);
	GPIO_InitTypeDef GPIO_InitStruct = {0};
	HAL_GPIO_WritePin(GPIOB, GPIO_PIN_7, GPIO_PIN_RESET);
	GPIO_InitStruct.Pin = GPIO_PIN_7;
	GPIO_InitStruct.Mode = GPIO_MODE_OUTPUT_PP;
	GPIO_InitStruct.Pull = GPIO_NOPULL;
	HAL_GPIO_Init(GPIOB, &GPIO_InitStruct);
	HAL_Delay(33);
	HAL_GPIO_DeInit(GPIOB,GPIO_PIN_7);

	HAL_I2C_Init(&hi2c1);
	HAL_Delay(250);

}
/* USER CODE END 0 */

/**
  * @brief  The application entry point.
  * @retval int
  */
int main(void)
{
  /* MCU Configuration--------------------------------------------------------*/

  /* Reset of all peripherals, Initializes the Flash interface and the Systick. */
  HAL_Init();

  /* Configure the system clock */
  SystemClock_Config();

  /* Initialize all configured peripherals */
  MX_GPIO_Init();
  MX_I2C1_Init();
  MX_USART2_UART_Init();
  /* USER CODE BEGIN 2 */
  HAL_Delay(1000);
  uint8_t str[] = "MLX90614\n\r";
  HAL_UART_Transmit_IT(&huart2, str, sizeof(str));
  HAL_Delay(100);
  mlx_sleep();
  mlx_wakeup();
  HAL_Delay(500);
  memset(uart_buf,0,30);
  sprintf(uart_buf, "temperature : ---\n\r");
  HAL_UART_Transmit_IT(&huart2, uart_buf, sizeof(uart_buf));
  /* USER CODE END 2 */

  /* Infinite loop */
  /* USER CODE BEGIN WHILE */
  while (1)
  {
	  mlx_read_temperature();
	  HAL_Delay(1000);
    /* USER CODE END WHILE */

    /* USER CODE BEGIN 3 */
  }
  /* USER CODE END 3 */
}

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


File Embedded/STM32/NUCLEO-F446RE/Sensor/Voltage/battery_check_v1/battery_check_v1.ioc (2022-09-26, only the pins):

Mcu.UserName=STM32F446RETx
PA2.Signal=USART2_TX
PA3.Signal=USART2_RX
PC5.Signal=ADCx_IN15

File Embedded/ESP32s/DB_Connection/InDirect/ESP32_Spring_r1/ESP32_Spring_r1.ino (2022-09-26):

#include "CRUD.h"
#include "Credentials.h"

unsigned long lastTime = 0;
unsigned long timerDelay = 5000;

void setup() {
  Serial.begin(115200);

  WiFi.begin(ssid, password);
  Serial.println("Connecting");
  while(WiFi.status() != WL_CONNECTED) {
    delay(500);
    Serial.print(".");
  }
  Serial.println("");
  Serial.print("Connected to WiFi network with IP Address: ");
  Serial.println(WiFi.localIP());
  Serial.println("Timer set to 5 seconds (timerDelay variable), it will take 5 seconds before publishing the first reading.");
}

void loop() {
  if ((millis() - lastTime) > timerDelay) {
    //Check WiFi connection status
    if(WiFi.status()== WL_CONNECTED){
      Post();
    }
    else {
      Serial.println("WiFi Disconnected");
    }
    lastTime = millis();
  }
}

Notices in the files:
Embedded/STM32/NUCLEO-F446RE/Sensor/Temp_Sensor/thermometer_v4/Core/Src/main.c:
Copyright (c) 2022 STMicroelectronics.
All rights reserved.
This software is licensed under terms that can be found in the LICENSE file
